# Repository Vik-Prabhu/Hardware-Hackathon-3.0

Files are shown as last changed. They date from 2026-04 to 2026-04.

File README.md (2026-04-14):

# 1. Title of the project
**Green Node**

# 2. Problem Statement
The global agricultural sector faces a massive adoption gap in precision agriculture. Out of over 500 million small farms globally, only about 10% use digital agricultural services.
- **Prohibitive Costs**: Commercial sensor nodes cost upwards of $200–$250 per unit, with traditional cellular IoT incurring high recurring costs and requiring expensive trenching.
- **Hardware Failures**: Many existing solutions fail in harsh agricultural environments, suffering from battery death during cold snaps or UV degradation.
- **Sensor Inaccuracies**: Low-cost sensors claim to measure nutrients but actually measure soil electrical conductivity, leading to high inaccuracies.
- **Data Fatigue**: Farmers are overwhelmed with raw data rather than actionable insights.
- **Yield vs. Money Disconnect**: Agritech often visualizes agronomy but fails to show economic impact.

# 3. Objective
To build a low-cost, scalable, and open-source plantation monitoring system for the Hardware Hackathon 3.0. Green Node merges robust hardware edge nodes with a sophisticated AI advisory pipeline to bring state-of-the-art agricultural monitoring to farmers. Our core objective focuses on plant survival, optimal yield, and early disease prevention through high-accuracy local ground truth.

# 4. Existing work
The current market is split between expensive agricultural tech and software-heavy platforms lacking local ground truth:
| Competitor | Approach | Weakness |
|---|---|---|
| **Fasal** | Farm-specific IoT | Very high hardware cost, vertical-specific |
| **CropIn** | Software-only platform | No on-ground sensors (estimations only) |
| **Manual Contractors**| Schedule-based inspection | Inefficient, unaccountable |

# 5. Gap analysis
Despite the rise of precision agriculture, competitors fail due to **scaling constraints and disconnected methodologies**. Existing systems lack integration between cheap continuous ambient measurement and deep-learning visual diagnostics. Solutions like Fasal capture field data but demand massive capital ($200+ unit cost), while CropIn relies purely on estimates without true real-world soil/plant mapping. 

Green Node bridges this gap by decoupling continuous soil telemetry from computationally heavy vision tasks—delivering a comprehensive package for under ₹2,400 per node, combined with actionable, real-time AI-guided triaging devoid of monthly LTE service drops.

# 6. Novelty
The core novelty resides in our **Dual-Node Architecture linked to an AI Advisory Pipeline**:
Instead of providing raw datasets like "humidity is 78%", Green Node features a visual capture layer. The camera node feeds leaf images into an AI model combined with live ambient data. The system generates intelligent, multi-lingual daily action priorities—e.g., *"Node 3 has early signs of Late Blight — inspect row 4."*
Additionally, we leverage **Dynamic Sentinal Polling**: Sensor nodes dynamically change their reporting frequency based on internal thresholds (e.g. accelerating ping rates from 30s to 5s during severe moisture drops).

# 7. Your project description
Green Node is a fully integrated ecosystem designed to deliver actionable intelligence. It incorporates:
1. **Hardware Edge Nodes:** Custom-designed PCB routing, deploying ESP32-C3 for continuous environmental tracking (temperature, humidity, moisture, light) and ESP32-CAM nodes for visual plant health assessments.
2. **Comprehensive Data Backend:** Built with FastAPI and an SQLite embedded database to handle data ingestion over local Wi-Fi without internet cellular reliance.
3. **AI Health Advisory Pipeline:** Contextually combined sensor data and visual image scans generate daily Action Plans translated into Tamil, Telugu, Kannada, Hindi, and Bengali using Sarvam AI, complete with audio TTS capabilities.
4. **Earthy Editorial Dashboard:** A fully responsive bespoke dashboard providing clear, animated, high-end insights for the modern facility or farmer.

# 8. List of components and the software used
### Hardware Components
* **MCU:** ESP32-C3 Dev Module (RISC-V) & AI-Thinker ESP32-CAM (ESP32-S).
* **Sensors:** DHT11 / DHT22 (Temperature & Humidity), Capacitive Soil Moisture Sensor v1.2, GL5528 LDR (Ambient Light), OV2640 (2MP Camera).
* **Power:** 5V/3.3V custom regulating PCB headers.

### Software Stack
* **Microcontroller Firmware:** C++ (Arduino Framework), `DHT sensor library`, `ArduinoJson`.
* **Backend Core:** Python (FastAPI, Uvicorn, APScheduler), SQLite.
* **Frontend Design:** Vue.js / VitePress / HTML interfaces.
* **Microservices:** Gemini Vision models natively proxied through a Sarvam AI API pipeline for multilingual translation and audio rendering.

# 9. Methodology
To validate our system in a real-world edge scenario, we deployed it in a live indoor bonsai nursery:
- **Node N-01 (Camera + Env Node):** Captured on-demand 800×600 SVGA SVGA imagery alongside DHT22 inputs whenever the server requested.
- **Node N-02 (Soil Node):** Pushed telemetry continuously every 30 seconds via HTTP POST, adjusting frequency whenever threshold rules were broken.
Data is sent explicitly through local WiFi `mDNS` structures routing directly to a secure, localized central Python Hub—acting as a firewall from public internet threats.

# 10. Work flow
1. **Boot Sequence:** Both nodes power up, synchronize UTC timing via NTP, and POST their IPs to `vikram-Vivobook-Go.local:8000/register`. 
2. **Measurement Cycle (Continuous):** The Soil Node (N-02) wakes, tracks variables, and evaluates internal thresholds to set loop delays (5s vs 30s) before executing an HTTP POST with JSON data.
3. **Capture Cycle (Pull):** The central server queries the Vision Node (N-01) at `GET /capture`. The node streams a JPEG byte packet alongside `X-Moisture` and `X-Temperature` custom headers.
4. **AI Inference & Translation:** The local Hub fuses the image and historical sensor values, passing it to an AI proxy. Sarvam AI retrieves the analysis, translating the diagnostic into local languages.
5. **Dashboard Reflection:** The end-user operates the Vue dashboard reading the localized `Daily Action Plan`.

# 11. Pic of the project/ prototype
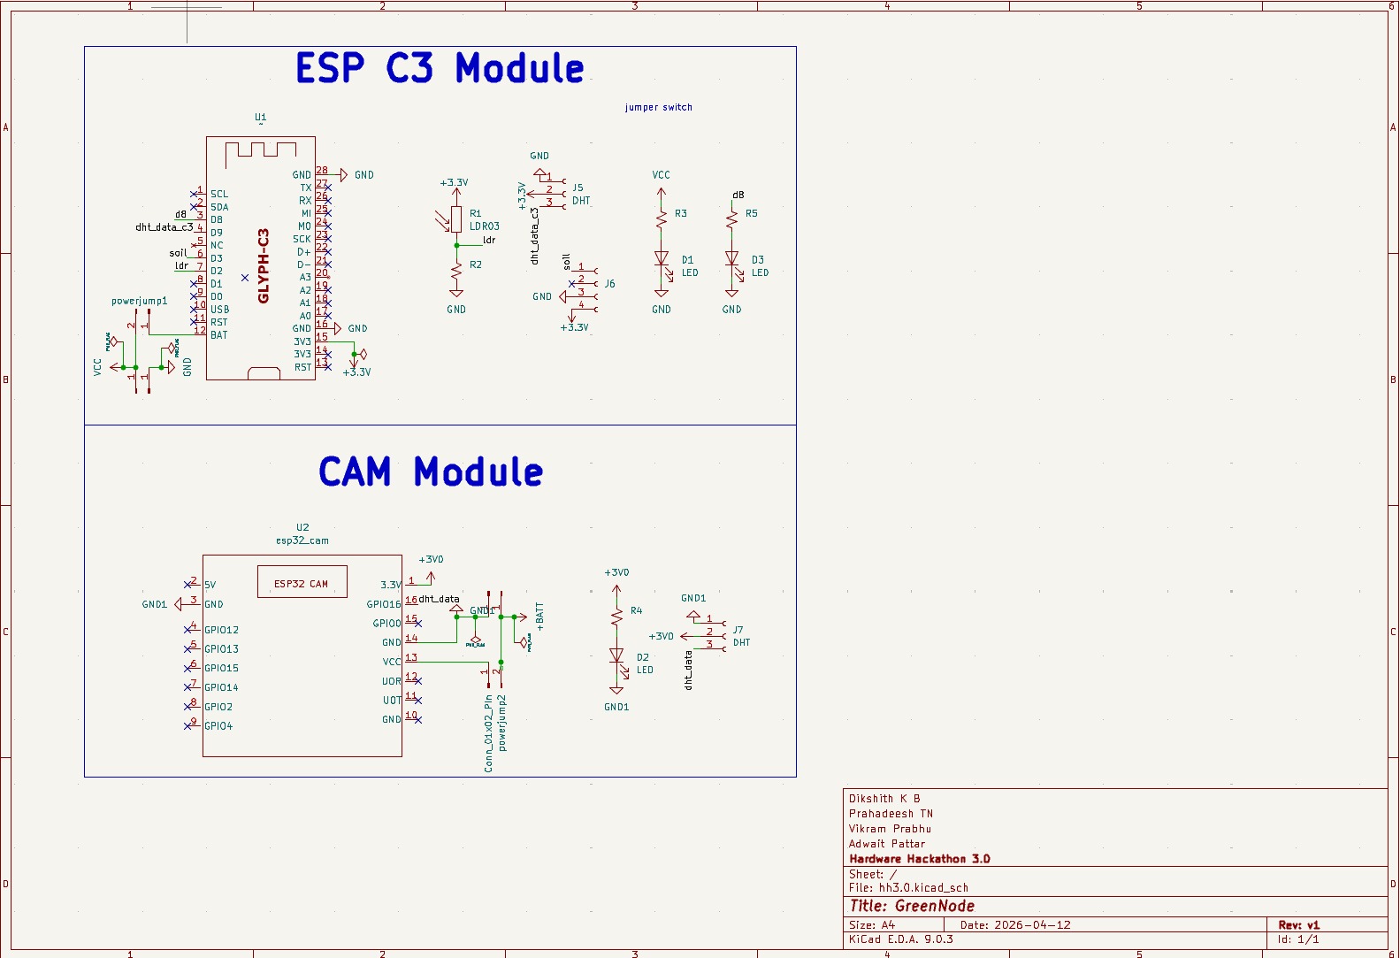
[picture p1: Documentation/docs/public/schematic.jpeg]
Green Node PCB Schematic

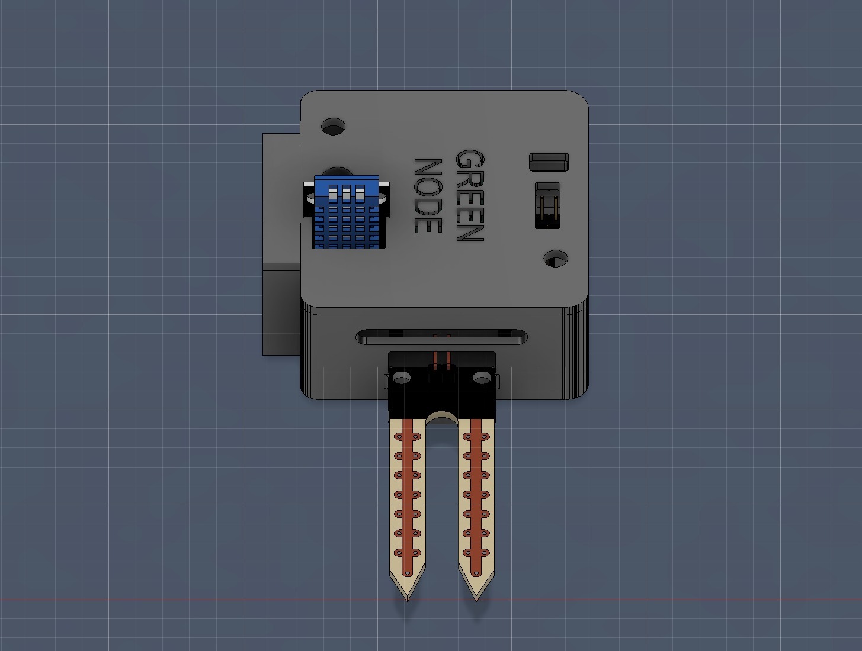
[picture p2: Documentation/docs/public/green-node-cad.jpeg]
Green Node CAD Housing


# 12. Demo video
*[Insert Link to Live Project Demo Video Here]*

# 13. Create a public github repo and attach the following
*The current repository encompasses the complete documentation, firmware, server environment, and backend code designed explicitly according to the 13-point rubric constraints.*
**Repository URL**: [https://github.com/Vik-Prabhu/Hardware-Hackathon-3.0](https://github.com/Vik-Prabhu/Hardware-Hackathon-3.0)

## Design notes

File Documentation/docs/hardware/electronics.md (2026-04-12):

# Electronics & Schematics

The Green Node PCB was designed in **KiCad 9.0.3** as a single-sheet schematic (`hh3.0.kicad_sch`) housing two independent sensor modules on one board. The design prioritises minimal component count, through-hole assembly, and modular sensor connectors.

## Full Schematic

Green Node PCB Schematic — Rev v1

---

## ESP C3 Module (Node N-02)

The upper section of the schematic is built around **U1 — GLYPH-C3**, an ESP32-C3 RISC-V module. It handles continuous soil, light, temperature, and humidity monitoring.

### Pin Assignments

| GLYPH-C3 Pin | Net | Connected To |
|:---:|---|---|
| D8 | `dB` | Status LED D3 via R5 (current-limiting) |
| D9 (dht_data_c3) | `dht_data_c3` | **J5** — DHT11 sensor, pin 2 (data) |
| A0 (soil) | `soil` | **J6** — Capacitive Soil Moisture Sensor, pin 1 (analog out) |
| A1 (ldr) | `ldr` | **R1 (LDR03)** — LDR voltage divider mid-point |
| D+ / D− | USB | On-board USB-C for programming |
| 3V3 | `+3.3V` | Regulated 3.3 V rail |
| GND | `GND` | Common ground |
| BAT | — | Battery input (unused in current revision) |

### Sensor Circuits

#### DHT11 — Temperature & Humidity (J5)
- **Connector:** 3-pin header (J5)
  - Pin 1 → `+3.3V`
  - Pin 2 → `dht_data_c3` (GPIO 9)
  - Pin 3 → `GND`
- **Pull-up:** R3 (10 kΩ) from data line to VCC

#### LDR — Ambient Light (R1)
- **R1 (LDR03)** forms a voltage divider with **R2** (10 kΩ fixed) between `+3.3V` and `GND`
- Mid-point tap connects to **A1** (GPIO 2) for analog read
- ADC maps the 0–3.3 V range to a 12-bit value (0–4095)

#### Capacitive Soil Moisture Sensor (J6)
- **Connector:** 4-pin header (J6)
  - Pin 1 → analog signal → `soil` (GPIO 3)
  - Pin 2 → `GND`
  - Pin 3 → `GND`
  - Pin 4 → `+3.5V` (sensor power)
- Corrosion-resistant capacitive probe; no direct soil contact on electrodes

#### Status LEDs (D1, D3)
- **D1** and **D3** are indicator LEDs driven through current-limiting resistors **R3** and **R5**
- Connected to GPIO `dB` for visual status feedback

### Power
- **powerjump1** — 2-pin power header providing `VCC` and `GND` from external supply
- **Jumper switch** at the top of the sheet controls main power to the C3 module
- The on-board LDO regulates input down to `+3.3V` for the MCU and sensors

---

## CAM Module (Node N-01)

The lower section is built around **U2 — ESP32-CAM** (AI-Thinker). It captures plant images on demand and reads ambient temperature via a DHT22 sensor.

### Pin Assignments

| ESP32-CAM Pin | Net | Connected To |
|:---:|---|---|
| 5V | `+5V` | External power input |
| GND | `GND1` | Common ground |
| 3.3V | `+3V0` | Regulated 3.3 V output |
| GPIO16 | `dht_data` | **J7** — DHT22 sensor, pin 2 (data) |
| GPIO0 | — | Boot mode select (active-low for flash) |
| U0R / U0T | UART | Serial programming via FTDI adapter |
| GPIO12–15, GPIO2, GPIO4 | — | Directly to camera data bus (active only on high-density header internally to the ESP32-CAM) |

### Sensor Circuits

#### DHT22 — Temperature & Humidity (J7)
- **Connector:** 3-pin header (J7)
  - Pin 1 → `GND1`
  - Pin 2 → `dht_data` (GPIO 16 → routed to GPIO 13 in firmware via internal mapping)
  - Pin 3 → `+3V0`
- **Pull-up:** R4 (10 kΩ) from data line to `+3V0`

#### Status LED (D2)
- Single indicator LED tied to `+3V0` through a current-limiting resistor
- Provides visual power-on feedback

### Power
- **powerjump2** — 2-pin Conn_01x02 header providing `+BATT` and `GND` from an external source
- The ESP32-CAM's on-board AMS1117 regulates 5 V input down to 3.3 V for the MCU and camera

::: warning Camera Pin Conflict
On the AI-Thinker ESP32-CAM, GPIOs 32–39 are **all consumed** by the OV2640 camera data bus. Analog sensors (soil moisture, LDR) cannot share this module and require an external I²C ADC (e.g. ADS1115) or a dedicated MCU like the GlyphC3 above.
:::

---

## Design Notes

| Parameter | Detail |
|---|---|
| **EDA Tool** | KiCad E.D.A. 9.0.3 |
| **Schematic File** | `hh3.0.kicad_sch` |
| **Sheet** | 1/1 (single sheet) |
| **Board Size** | A4 |
| **Revision** | v1 |
| **Date** | 2026-04-12 |
| **Designed by** | Dikshith K B, Prahadeesh TN, Vikram Prabhu, Adwait Pattar |

### Key Design Decisions
- **Modular sensor connectors (J5, J6, J7):** All sensors use standard pin headers so they can be swapped, replaced, or upgraded without rework
- **Separate power domains:** The C3 module runs on 3.3 V while the CAM module accepts 5 V, each with independent power jumpers for isolation during debugging
- **Through-hole assembly:** All connectors and passives are through-hole for ease of hand-soldering during rapid prototyping
- **Status LEDs on each module:** D1/D3 on the C3 side and D2 on the CAM side provide immediate visual feedback without requiring serial monitor access

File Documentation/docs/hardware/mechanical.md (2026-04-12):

# Mechanical Design

The mechanical design of the **Green Node** focuses on durability, compactness, and ease of assembly. The enclosure is designed to house the core electronics, sensors, and power management systems while providing adequate exposure out to the environment.

## 3D CAD Enclosure

The render below illustrates the assembly of the primary tracking node, integrating our key sensors directly into the structural housing.

Green Node CAD Assembly

### Mechanical Features
- **Integrated Environment Sensor (DHT11):** Protrudes gracefully from the side port to ensure the sensor captures ambient temperature and humidity seamlessly, free from any internal thermal interference.
- **Direct Soil Probing:** The soil moisture sensor is securely bottom-mounted, allowing the entire node to be easily pegged directly into the dirt.
- **Robust Casing:** The main body features heavy-duty styling with the "GREEN NODE" branding engraved cleanly on the surface.

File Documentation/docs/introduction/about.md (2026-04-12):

# About Our Project: Green Node

Welcome to **Green Node**, an advanced, open-source plantation monitoring system built for the Hardware Hackathon 3.0. We are building a comprehensive ecosystem that merges robust hardware edge nodes with a sophisticated AI advisory pipeline to bring state-of-the-art agricultural monitoring to your fingertips.

## Project Showcase

Our solution is divided into distinct, seamlessly integrated components:

### 1. Hardware Edge Nodes
At the core of the Green Node system are our custom-designed hardware nodes, leveraging reliable microcontrollers for real-world deployment:
- **GlyphC3 Sensor Nodes (ESP32-C3):** Engineered for continuous environmental tracking, these nodes gather precise temperature and humidity metrics using minimal power.
- **Vision Nodes (ESP32-CAM):** Equipped with camera modules, these nodes capture visual data of the plantation to enable visual health assessments.

### 2. Comprehensive Data Backend
Built with FastAPI and an SQLite embedded database, the robust backend architecture handles data ingestion from multiple distributed nodes via Wi-Fi network and HTTP. It offers a fully-featured RESTful API to manage the continuous stream of sensor metrics and images.

### 3. AI Health Advisory Pipeline
We integrate leading AI models to analyze the plantation's status:
- Using image and sensor data context, we generate a daily **AI Health Advisory** for the plantation.
- **Multilingual Support:** Powered by the Sarvam AI API, the dashboard provides a daily action plan translated into multiple regional languages, complete with integrated text-to-speech (TTS) playback to make the advisory accessible to every farmer.

### 4. Earthy Editorial Dashboard
All this data is visualized through our beautifully designed Green Node dashboard. Built with an earthy, modern, and editorial design language, the dashboard features:
- Interactive live sensor data
- Scroll-triggered animations and a premium glassmorphic UI
- Actionable AI-driven insights directly in the interface

We are passionate about bringing modern technology to agriculture efficiently, reliably, and elegantly. Explore the rest of the documentation to dive deeper into our hardware architecture, software stack, and implementation methodology!

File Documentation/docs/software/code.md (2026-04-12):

# Software & Firmware

> **Node Documentation** | ESP32-CAM & Soil Sensor Nodes
> 
> *Distributed passive system communicating via HTTP to a central Python server.*

---

# Software & Firmware

Two independent firmware builds run on two dedicated nodes. Both are passive — they respond
to the central Python server rather than pushing data on their own schedule.

**Camera Node** (AI-Thinker ESP32-CAM) — captures leaf images and ambient DHT22 readings on server trigger.

**Soil Node** (ESP32-C3) — continuously measures soil moisture, temperature, humidity, and light,
posting readings to the server on a dynamic interval.

---

## Part 1 — Camera Node (AI-Thinker ESP32-CAM)

### How It Works

The node connects to WiFi, registers its IP with the server, then idles — the loop only
handles incoming HTTP requests and retries registration if needed.

On `GET /capture` the node reads the DHT22, grabs a JPEG from the OV2640, streams the image
back as `image/jpeg`, and attaches sensor values as custom response headers.
No push, no polling loop — the server decides when to trigger.

### Configuration

```cpp
#define WIFI_SSID          "Vik"
#define WIFI_PASSWORD      "qwertyui"
#define SERVER_HOST        "vikram-Vivobook-Go.local"
#define SERVER_PORT        8000
#define NODE_ID            "N-01"
#define WIFI_CONNECT_TIMEOUT  20000
#define REGISTER_RETRY_DELAY  10000
```

`SERVER_HOST` is resolved via mDNS — the server machine must run Avahi (Linux) or Bonjour (macOS/Windows).

### GPIO Constraints

The OV2640 occupies GPIOs 0, 5, 18, 19, 21–27, 32, 34–36, 39 on the AI-Thinker board.
GPIOs 34–39 are also the ESP32's ADC1 pins, so **`analogRead()` cannot be used for any
analog sensor on this board.** The only free pin for an external sensor is **GPIO 13**,
used by the DHT22.

> Soil moisture and battery voltage require a separate node (Part 2) or an external
> I2C ADC (e.g. ADS1115). Currently `moisture` is aliased to DHT humidity and `battery`
> is hardcoded to `100.0`.

### DHT22 — GPIO 13

```cpp
#define DHT_PIN   13
#define DHT_TYPE  DHT22

float temperature = dht.readTemperature();
float humidity    = dht.readHumidity();

if (isnan(temperature)) temperature = 0.0;
if (isnan(humidity))    humidity    = 0.0;
```

Readings are taken synchronously inside `/capture`. The DHT22's 2-second minimum sample
interval is naturally respected since captures are server-triggered, not continuous.

### Camera Initialisation

Resolution and buffer count are chosen at runtime based on PSRAM availability:

```cpp
if (psramFound()) {
    config.frame_size   = FRAMESIZE_SVGA;   // 800×600
    config.jpeg_quality = 12;
    config.fb_count     = 2;
} else {
    config.frame_size   = FRAMESIZE_VGA;    // 640×480
    config.jpeg_quality = 14;
    config.fb_count     = 1;
}
```

SVGA is preferred over UXGA — higher resolutions cause allocation failures on this board
without PSRAM. Clock is set to 10 MHz (default is 20 MHz) to reduce heat on the module.

After init, auto-exposure, auto-gain, and auto-white-balance are enabled via the sensor register
API. Five warm-up frames are then discarded to let AEC and AWB settle.

### HTTP Endpoints

#### `GET /capture`

1. Returns `503` immediately if a capture is already in progress
2. Reads DHT22
3. Calls `esp_camera_fb_get()` — retries once with a 500 ms delay on failure
4. Sends JPEG with sensor data as response headers
5. Returns frame buffer and clears the `capturing` flag

```cpp
localServer.sendHeader("X-Moisture",    String(moisture, 1));
localServer.sendHeader("X-Temperature", String(temperature, 1));
localServer.sendHeader("X-Battery",     String(battery, 1));
localServer.sendHeader("X-Node-ID",     NODE_ID);
```

Image is streamed in 4096-byte chunks to avoid stalling the WiFi stack.

Possible responses: `200 image/jpeg` on success, `500` if the camera failed, `503` if busy.

#### `GET /health`

Liveness check — no capture triggered. Returns:

```json
{
  "node_id": "N-01",
  "camera": true,
  "capturing": false,
  "uptime": 3742,
  "free_heap": 186432,
  "ip": "192.168.1.105"
}
```

### Server Registration

On boot (and every 10 s while unregistered), the node POSTs its IP:

```
POST http://vikram-Vivobook-Go.local:8000/node/N-01/register
{"ip": "192.168.1.105"}
```

If the server is offline at boot, the node retries silently until it responds.
WiFi drops also reset `registered = false`, triggering re-registration after reconnect.

### Flashing

**Arduino IDE dependencies:** `esp32` board package (Espressif, v2.0.x+),
`DHT sensor library` by Adafruit, `Adafruit Unified Sensor`.

**Board settings:** AI Thinker ESP32-CAM · Upload Speed 115200 · Partition: Huge APP (3MB No OTA).

The ESP32-CAM has no onboard USB. Wire an FTDI FT232RL adapter:

```
FTDI 3.3V  →  ESP32-CAM 3.3V
FTDI GND   →  ESP32-CAM GND
FTDI TX    →  GPIO 3  (U0R)
FTDI RX    →  GPIO 1  (U0T)
FTDI GND   →  IO0     ← hold LOW during flash only
```

Hold IO0 low → press reset → upload → disconnect IO0 → press reset to run.

---

## Part 2 — Soil Sensor Node (ESP32-C3)

### How It Works

Unlike the camera node, the soil node is **push-based** — it wakes on a timer, reads all
four sensors, and POSTs a JSON payload to the server. The send interval is dynamic:
30 seconds under normal conditions, dropping to 5 seconds when soil moisture goes critical.
The server can also override the interval by returning a `next_sleep_min` field in its response.

### Configuration

```cpp
#define PIN_SOIL_MOISTURE   3
#define PIN_LDR             2
#define PIN_DHT             9
#define DHT_TYPE            DHT11

#define SEND_INTERVAL_NORMAL_MS    (30UL * 1000)
#define SEND_INTERVAL_CRITICAL_MS  (5UL  * 1000)
#define MOISTURE_CRITICAL          25

#define WIFI_SSID     "Vik"
#define WIFI_PASSWORD "qwertyui"
#define SERVER_HOST   "vikram-Vivobook-Go.local"
#define SERVER_PORT   8000
#define NODE_ID       "N-02"
```

### Sensors

#### Soil Moisture — GPIO 3 (analog)

Raw ADC output (0–4095) is mapped to a 0–100% scale and inverted — higher raw value
means drier soil on a resistive sensor:

```cpp
int rawSoil   = analogRead(PIN_SOIL_MOISTURE);
data.moisture = (float)constrain(map(rawSoil, 4095, 0, 0, 100), 0, 100);
```

#### Temperature & Humidity — DHT11 on GPIO 9

```cpp
data.humidity    = dht.readHumidity();
data.temperature = dht.readTemperature();
if (isnan(data.humidity))    data.humidity    = 0.0;
if (isnan(data.temperature)) data.temperature = 0.0;
```

Note: DHT11 is used here (not DHT22) — ±2°C and ±5% RH accuracy. Upgrade to DHT22 for
tighter tolerances.

#### Light — LDR on GPIO 2 (analog, GL5528-style)

The LDR sits in a voltage divider with a 100 kΩ pull-down resistor. The ADC reading is
converted to lux through three steps:

```cpp
// 1. ADC counts → voltage at the ADC pin
float v_adc = rawLDR * (LDR_SUPPLY_V / 4095.0f);

// 2. Voltage divider → LDR resistance (LDR between VCC and ADC pin)
float r_ldr = (v_adc > 0.01f)
              ? LDR_PULLDOWN_OHM * (LDR_SUPPLY_V - v_adc) / v_adc
              : 1000000.0f;  // clamp in total darkness

// 3. Power-law model → Lux
// GL5528 characteristic: R_ldr = A × lux^B  →  lux = (R_ldr / A)^(1/B)
float lux = pow(r_ldr / LDR_A, 1.0f / LDR_B);
lux = constrain(lux, 0.0f, 100000.0f);
data.light = (int)lux;
```

Power-law constants used:

```cpp
#define LDR_A  32017.558f   // resistance at reference illuminance (Ω)
#define LDR_B  -0.7f        // slope exponent (negative: more light = less resistance)
```

These are fit to a GL5528 characteristic curve. Recalibrate `LDR_A` and `LDR_B` against
a reference lux meter if accuracy matters.

#### Battery

Currently hardcoded to `100`. Replace with a real ADC read through a resistor divider
when a battery circuit is added.

### Dynamic Send Interval

After every read, the node checks moisture against the critical threshold and adjusts
its interval before posting:

```cpp
sendIntervalMs = (sd.moisture < MOISTURE_CRITICAL)
                 ? SEND_INTERVAL_CRITICAL_MS    // 5 s
                 : SEND_INTERVAL_NORMAL_MS;     // 30 s
```

The server can also push an interval override in the POST response:

```json
{ "next_sleep_min": 10 }
```

If present, `next_sleep_min` (in minutes) overrides the local calculation for the next cycle.

### HTTP POST — `/node/N-02/sensor`

```json
{
  "moisture":    45.0,
  "temperature": 26.2,
  "humidity":    60.0,
  "light":       3200,
  "battery":     100.0,
  "timestamp":   "2026-04-11T12:00:00Z"
}
```

`timestamp` is an ISO 8601 UTC string generated from NTP-synced system time.
If the POST fails, the node retries once after 1 second before moving on.

### NTP Time Sync

The node syncs its clock immediately after WiFi connects in `setup()`:

```cpp
configTime(0, 0, "pool.ntp.org", "time.nist.gov");
```

Timestamps are formatted as ISO 8601 UTC:

```cpp
char buf[25];
strftime(buf, sizeof(buf), "%Y-%m-%dT%H:%M:%SZ", &t);
```

If NTP fails (10-second timeout), timestamps fall back to `"1970-01-01T00:00:00Z"`.

### Main Loop

```cpp
void loop() {
  if (millis() < nextSendTime) return;  // idle until interval expires

  ensureWiFiConnected();
  SensorData sd = readSensors();

  // pick interval based on moisture level
  sendIntervalMs = (sd.moisture < MOISTURE_CRITICAL)
                   ? SEND_INTERVAL_CRITICAL_MS
                   : SEND_INTERVAL_NORMAL_MS;

  long serverInterval = sendData(sd);
  if (serverInterval == -1) {          // retry once on failure
    delay(1000);
    serverInterval = sendData(sd);
  }
  if (serverInterval > 0)
    sendIntervalMs = (unsigned long)serverInterval;

  nextSendTime = millis() + sendIntervalMs;
}
```

The loop body runs only when `millis()` reaches `nextSendTime` — no `delay()` blocking,
no RTOS tasks. WiFi reconnection is handled inline before every read cycle.

### Flashing

**Arduino IDE dependencies:** `esp32` board package (Espressif), `DHT sensor library` by Adafruit,
`Adafruit Unified Sensor`, `ArduinoJson` by Benoit Blanchon.

**Board settings:** ESP32C3 Dev Module · Upload Speed 115200 · USB CDC On Boot: Enabled.

The ESP32-C3 has a native USB-Serial bridge — no FTDI adapter needed. Connect via USB,
select the correct COM port, and upload directly.

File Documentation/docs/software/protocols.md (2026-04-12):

# Communication Protocols

This document outlines the architecture, data flows, and security mechanisms of the communication protocols utilized in the Hardware Hackathon system.

## 📡 Core Protocol Architecture

The system operates primarily on **HTTP/1.1** over IPv4 TCP/IP, broadcasted over an IEEE 802.11 (WiFi) local network. We chose standard HTTP for its simplicity, ease of debugging, and strong compatibility with the FastAPI backend and ESP32 `WebServer` / `HTTPClient` frameworks.

In addition to HTTP, **mDNS (Multicast DNS)** is optionally configured for localized server-node discovery without hardcoding dynamic IPs.

### Protocol Breakdown

#### 1. Node-to-Server Data Transmission (HTTP POST)
- **Data Format**: JSON Payload
- **Role**: ESP32 nodes periodically acquire sensor data (temperature, humidity, moisture, light) and serialize it.
- **Endpoint**: `/node/{node_id}/sensor`
- **Mechanism**: The ESP32 node acts as an HTTP client, making asynchronous `POST` requests to the FastAPI backend. Nodes also announce their presence via a periodic `/node/{node_id}/register` ping so the server can track dynamic local IP assignments.

#### 2. Server-to-Node Polling (HTTP GET)
- **Data Format**: Image stream (JPEG/Multipart) & Metadata in Custom HTTP Headers
- **Role**: The backend server can remotely trigger a photo capture for vision-enabled nodes (`esp32cam_node`).
- **Endpoint (on Node)**: `http://{node_ip}/capture`
- **Mechanism**: The FastAPI server acts as an HTTP Client, sending requests to the embedded WebServer concurrently running on the ESP32. The node replies with a raw JPEG byte stream. Essential sensor metadata is bundled directly into the outbound `HTTP Headers` (e.g., `X-Moisture`, `X-Temperature`) to save bandwidth and simplify parsing.

#### 3. Client-to-Server Dashboard API (HTTP)
- **Data Format**: RESTful JSON API
- **Role**: The VitePress front-end dashboard fetches historical logs, AI advisories, real-time alerts, and captures.
- **Mechanism**: Standard `GET` and `POST` requests utilizing browser-native `fetch`.

#### 4. Server-to-AI Microservices (HTTP / HTTPS)
- **Data Format**: JSON & Multipart Form Data
- **Role**: Offloads logic to heavier deep-learning models for image/sensor analysis and multi-lingual translation.
- **Mechanism**:
  - **Internal AI API**: The backend forwards hardware requests to the local `AI_SERVER_URL` via proxy requests.
  - **External Cloud API**: Sarvam AI text translations are sent securely over the Wide Area Network (WAN) via `HTTPS` (`https://api.sarvam.ai/translate`).

---

## 🔒 Security & Safety Mechanisms

Given the constraints of Internet of Things (IoT) environments, network safety requires a combination of boundary fortification and internal resilience. Because this project is designed as an open-source, edge-computing blueprint deployed on private spaces, we prioritize internal segmentation and logical boundaries.

### 1. Isolated Network Topology
The sensor nodes are **never** exposed directly to the public internet. All nodes communicate *only* with the local Gateway (FastAPI server). The backend proxy acts as a firewall and orchestrator, shielding the microcontrollers from external attacks, port scanning, or malicious polling.

### 2. Transport Layer Security (HTTPS vs. HTTP)
- **Local Network**: Inter-node communication (ESP32 ↔ Local Server) uses plain `HTTP`. In heavily constrained devices (like standard ESP32 boards), encrypting every localized TCP packet payload incurs significant computational overhead, which drains battery and introduces latency. We mitigate the risk by relying entirely on the base **WPA2/WPA3 Wi-Fi encryption**. Packet-sniffing requires first circumventing the wireless router's security layer.
- **Outbound Traffic**: Any communication leaving the local edge network to hit external endpoints (e.g., the Sarvam AI Language API) is fully secured using **HTTPS (TLS 1.2/1.3)** to prevent MiTM (Man in the Middle) interception.

### 3. Rate Limiting and Resilience
- **Node Side (Non-Blocking)**: The firmware leverages a hardware timer & `millis()` architecture rather than `delay()`. If the server drops offline or an HTTP timeout occurs, the node gracefully abandons the connection and continues acquiring hardware metrics without freezing the execution loop.
- **Server Side (Asynchronous)**: The FastAPI server applies decoupled asynchronous handlers (`aiohttp`) with strict lifecycle bounds (e.g., local `ClientTimeout`). If an ESP32 node hangs mid-transmission due to signal attenuation, the server proactively drops the connection, preventing resource exhaustion and blocking.

### 4. Codebase Credential Hardening
- Platform secrets—like the `SARVAM_API_KEY` and remote endpoints `AI_SERVER_URL`—are kept strictly decoupled via environment variables (`.env`).
- Environment templates are inherently shielded. `git` enforces ignorance of `.env` files, prohibiting source-code credential leakage to GitHub. No sensitive token is embedded into the compiled Arduino binaries either.

---

## 📝 Network Flow Diagram

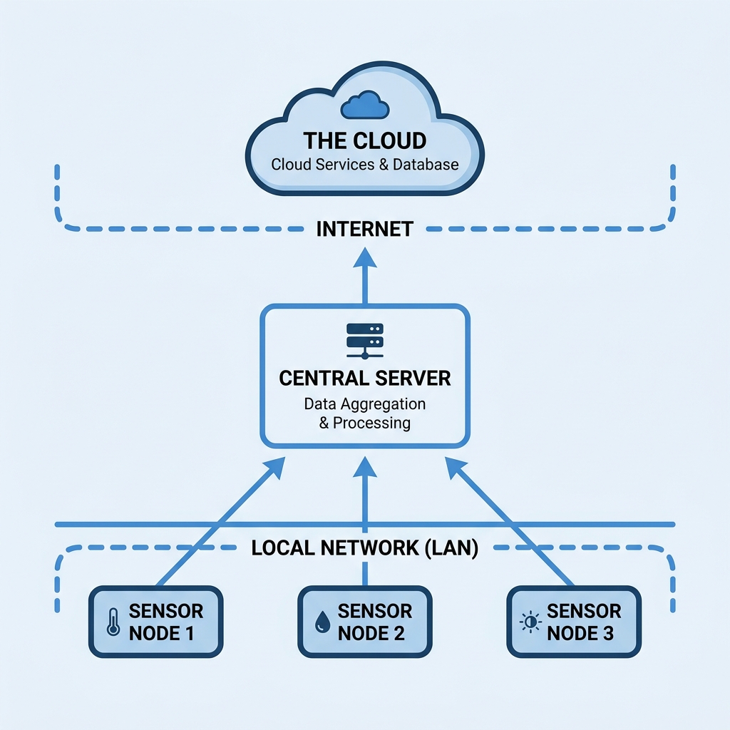
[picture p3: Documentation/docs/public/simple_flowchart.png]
Network Flowchart


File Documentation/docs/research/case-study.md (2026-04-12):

---
title: From Prototype to Product
description: How we evaluated our plant health monitoring system against a real-world product framework
sidebar_position: 3
---

# From Prototype to Product

Building something that works in a hackathon and building something that works in a field
for a paying customer are very different problems. This section documents how we stress-tested
our system against a structured product thinking framework — to be honest about what we've
built, what it's missing, and how it could scale.

---

## The Three Lenses

We evaluated the system through three lenses before calling it a product.

**Customer Lens** — Does it actually help the user succeed?
Our target users are farmers and greenhouse managers who don't have time for manual
crop inspection. The system needs to surface the right information at the right time,
without requiring the user to interpret raw sensor data themselves.

**System Lens** — Does it work reliably in the real world?
Because the hardware lives outdoors in soil and weather, reliability is non-negotiable.
A sensor that fails after two rain cycles is worse than no sensor — it creates false confidence.
Every design decision around enclosures, waterproofing, and sensor selection traces back to this.

**Business Lens** — Will users pay for it, and keep paying?
An AI insight that replaces a single agronomist visit has clear economic value.
We need to make sure the system delivers that value consistently enough that it becomes
a recurring part of how a farm operates, not a one-time experiment.

---

## What We're Actually Selling (Kotler's Product Model)

Mapping the system to Kotler's three-layer model forced us to be precise about
where our differentiation actually sits.

**Core Benefit**
Plant survival, optimal yield, and early disease prevention. This is the need we're selling
against — not hardware, not software.

**Expected Product**
At minimum, buyers expect the physical nodes to reliably capture soil moisture, temperature,
humidity, and light data. This is table stakes — any competitor can offer this.

**Augmented Product — our actual differentiator**
The camera node feeding leaf images into a pre-trained AI disease detection model is what
moves us out of the commodity tier. Instead of telling a farmer "humidity is 78%",
we tell them "Node 3 has early signs of Late Blight — inspect row 4."
That specificity is what justifies a price premium and creates switching costs.

---

## Architecture for Scale

We designed the system in three tiers so it can grow without a full rebuild.

**Tier 1 — Smart Connected Product**
Individual sensor nodes and camera nodes gathering real-time soil and plant data.
This is what we've built and what the MVP ships.

**Tier 2 — Product System**
A centralised platform where data from multiple nodes and the AI model aggregate
into a single farm health dashboard. Multiple farms, multiple node clusters,
unified view — this is the next 6-month target.

**Tier 3 — System of Systems (future)**
Integration with external data sources: weather APIs, automated irrigation controllers,
ERP systems used by large agricultural operations. The soil moisture reading triggers
a watering event. The disease detection flags a spray order. At this tier, the system
becomes infrastructure rather than a product.

---

## MVP Scope — MoSCoW Prioritisation

We used MoSCoW to define what Day 1 of a real deployment must include vs. what can wait.

**Must Have**
Soil moisture sensing accurate enough to trigger meaningful alerts.
AI leaf analysis that correctly identifies the most common disease classes.
A server that stores readings and surfaces alerts — even if the dashboard is basic.
Nodes that survive rain and outdoor temperatures for at least one growing season.

**Should Have**
Ambient humidity and light sensing for richer context around moisture readings.
NTP-synced timestamps so data aligns across multiple nodes.
Dynamic send intervals so the system reports more frequently when conditions are critical.

**Could Have**
Predictive disease modelling using time-series soil data, not just snapshot leaf images.
Battery voltage monitoring and low-battery alerts.
OTA firmware updates so deployed nodes don't need physical access to update.

**Won't Have (this iteration)**
LoRa or cellular connectivity — the current system requires local WiFi.
Automated irrigation actuation — we send alerts, we don't yet trigger hardware responses.
Full regulatory certification (CE, FCC) required for commercial distribution.

---

## Hardware Reality

Because we're shipping physical nodes, not just software, the manufacturing constraints
are part of the product definition — not an afterthought.

Components were chosen for immediate availability on standard supplier catalogues
(LCSC, Mouser, DFRobot) so the BOM can be sourced without long lead times.
The AI-Thinker ESP32-CAM and ESP32-C3 are both in mass production with stable supply.

For future commercial distribution, wireless modules operating in the 2.4 GHz and
sub-GHz bands require regional certification — CE for Europe, FCC for North America,
WPC for India. This is planned for after the MVP validation phase, once the core product
has been tested across at least two growing seasons in real field conditions.

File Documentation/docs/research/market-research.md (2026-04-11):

# Market Research & Business Plan

## Market Overview & Demand Drivers
The global agricultural and agritech sector is undergoing a massive transformation. Valued at approximately **$27.38 billion in 2023**, the market is projected to skyrocket to **$108.17 billion by 2032**. 
This growth is fundamentally driven by a surging global population—expected to reach 9.7 billion by 2050—which will require a 70% increase in food production. Simultaneously, maintaining green infrastructure and agricultural yields is increasingly challenging due to climate change, water scarcity, and declining pollinator populations.

## Gap in the Market: Why Competitors Fail
Despite the rise of precision agriculture, there is a massive adoption gap. Globally, out of over 500 million small farms, **only about 10% of smallholder farmers use digital agricultural services**. This gap is driven by critical pain points that Green Node is positioned to solve:

- **Prohibitive Costs & Scalability:** Commercial sensor nodes often cost upwards of $200–$250 per unit, making them inaccessible for large-scale deployments. Furthermore, traditional cellular IoT networks (LTE-M/NB-IoT) incur high recurring costs ($2–$10 per device monthly), and deploying grid power requires expensive trenching ($5,000–$25,000 per remote node).
- **Hardware Failures in the Field:** Many existing solutions fail in harsh agricultural environments. Battery-only sensors easily die during cold snaps, requiring expensive manual labor to replace them. Cheap solar panels rely on PET lamination that degrades and yellows within 18 months due to pesticide and UV exposure.
- **Sensor Inaccuracies:** The market is flooded with low-cost "NPK" sensors that claim to measure nutrients but actually just measure soil electrical conductivity, leading to highly inaccurate readings unless rigorously calibrated to specific local soils.
- **"Data Fatigue" & Poor UI/UX:** Farmers and facility managers are overwhelmed with raw data (e.g., raw soil moisture percentages) rather than actionable insights, leading to alert fatigue. Standard tech interfaces fail in the field because they lack offline functionality for connectivity "dead zones" and use interfaces that wash out under the harsh glare of midday sun.
- **The "Yield vs. Money" Disconnect:** Most Agritech apps excel at visualizing agronomy but fail to show the economic impact. A field might show "green" for health, but if the chemical inputs cost more than the saved crop, the user loses money.

## Target Market & Segments
Green Node addresses the inefficiency of schedule-based plant maintenance across multiple high-value segments:
- **Highway Medians (NHAI / PWD):** Replacing expensive tanker trips with data-driven irrigation across public infrastructure.
- **Commercial Nurseries:** Protecting high-value plant stock, reducing labor waste, and aiding export compliance through automated logs.
- **Urban Parks & Campuses:** Creating accountability for municipal contractors and large facilities with low staff overhead.
- **Controlled Environments:** Rooftop gardens and greenhouses requiring remote monitoring and precision care without on-site gardeners.

## Competitive Landscape
The current market is split between expensive agricultural tech and software-heavy platforms lacking local ground truth.

| Competitor | Approach | Weakness | Green Node Advantage |
|---|---|---|---|
| **Fasal** | Farm-specific IoT | Very high hardware cost, vertical-specific | General purpose, sub-₹2,400 node |
| **CropIn** | Software-only platform | No on-ground sensors (estimations only) | Actual sensor ground-truth |
| **Manual Contractors**| Schedule-based inspection | Inefficient, unaccountable | Route optimization & actionable data trail |

## SWOT Analysis

### Strengths
- **Low Hardware Cost:** Full node under ₹2,400; deployable at scale without massive upfront capital.
- **API & Sensor Synergy:** Combines real soil data with weather APIs for hyper-accurate, rain-aware irrigation.
- **Labor Optimization:** Route optimization solves a major workforce inefficiency (achieving ~75% time savings per shift), effectively tackling alert fatigue.

### Weaknesses
- **Sensor Tolerance Limits:** DHT11 ±2°C/±5% RH accuracy degrades in sustained high-humidity; demands upgrade (DHT22/SHT31) for extensive long-term deployments.
- **Local Range Constraints:** ESP-NOW caps at ~200m; requires relay modules for dispersed highway corridors.

### Opportunities
- **Government Procurement:** Active NHAI/PWD smart highway and green infrastructure mandates.
- **Export Compliance Tier:** Phytosanitary logs can unlock premium EU/US markets for partner nurseries.
- **Corporate ESG Integration:** Sponsored nodes for highway greenery by adjacent corporations seeking tangible CSR impact.

### Threats
- **Slow Sales Cycles:** Municipal or government procurement channels typically involve 12–18 month delays.
- **Environmental Hazard & Vandalism:** Nodes deployed in public spaces must endure physical tampering and brutal Indian monsoons (IP65 enclosures are critical).

## Financial Model & Cost Breakdown

**Unit Economics**
- **Grid-Powered Node:** ₹1,690 
- **Solar-Ready Node:** ₹2,790
- *Payback Period:* ~5 months assuming baseline SaaS pricing.

**Revenue Streams**
1. **Pilot Deployment (₹2–5 Lakh):** Initial 10 nodes including hardware, full installation, and 6-month dashboard data access.
2. **Subscription SaaS (₹500–800/node/month):** Predictable recurring revenue for dashboard, route prioritization, and automated alerts.
3. **Performance Contracts:** Revenue sharing model capturing 20% of the proven water bill reductions.
4. **Maintenance SLAs:** Annual hardware calibration and premium compliance reporting tiers.

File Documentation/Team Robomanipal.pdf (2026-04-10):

# Team RoboManipal

### Objective

We are building NurseryHub, an offline edge AI system that monitors every plant as an individual. We will design and implement a system capable of monitoring, maintaining, and controlling environmental conditions for plants within a nursery.

### Abstract and Plan

India has over 50,000 registered nurseries, the majority operating with fewer than five staff. Ornamental horticulture, tissue culture labs, bonsai collections, and grafting research stations all face the same constraint: biological systems with individual needs, managed by people whose attention is finite. GroveOS is not a gadget for a single plant on a windowsill. It is infrastructure for anyone who grows living things at scale and cannot afford to lose them.

A Maidenhair fern (Adiantum) can collapse in four hours when its soil dries below 60% in a nursery, whereas the Haworthia two benches over can tolerate 15% moisture for two weeks without complaining. The rootstock of a grafted rose requires a different level of hydration than the scion. If the temperature rises by two degrees above its comfortable range, a bud-set gardenia will abort every flower.

Soil moisture, temperature, humidity, ethylene, and CO2 are continuously measured by a network of modularized MCU nodes. The SBC hub fits a moisture decay curve to each plant's history to predict "water in 4 hours" rather than "water now," applies per-species thresholds (Calathea at 18% moisture fires an alert while cactus at 18% does not), and spreads disease risk through a spatial adjacency graph so that neighbors of a sick plant are flagged proactively before symptoms appear.

Sensors Sub Category Used-

- Temperature & Humidity
- Light & Colour
- Sound & Vibration
- Gas & Air Quality
- Soil & Moisture

Every morning the hub outputs a numbered walk route, the shortest path through all flagged plants, so two staff manage 200 plants purposefully instead of wandering.

The expected outcome is a nursery operating on a predictive rather than reactive model, with alert fatigue eliminated, disease spread caught early, and daily inspection time cut from two hours to under thirty minutes.

### Concept Category

- Microcontroller - ESP32
- SBC - Raspberry Pi
- Sensors - soil/moisture, temperature/humidity, gas/air quality
- Communication - Wi-Fi and BT
- Display - LCD
- Output Devices - addressable LED strips.

### Block Diagram

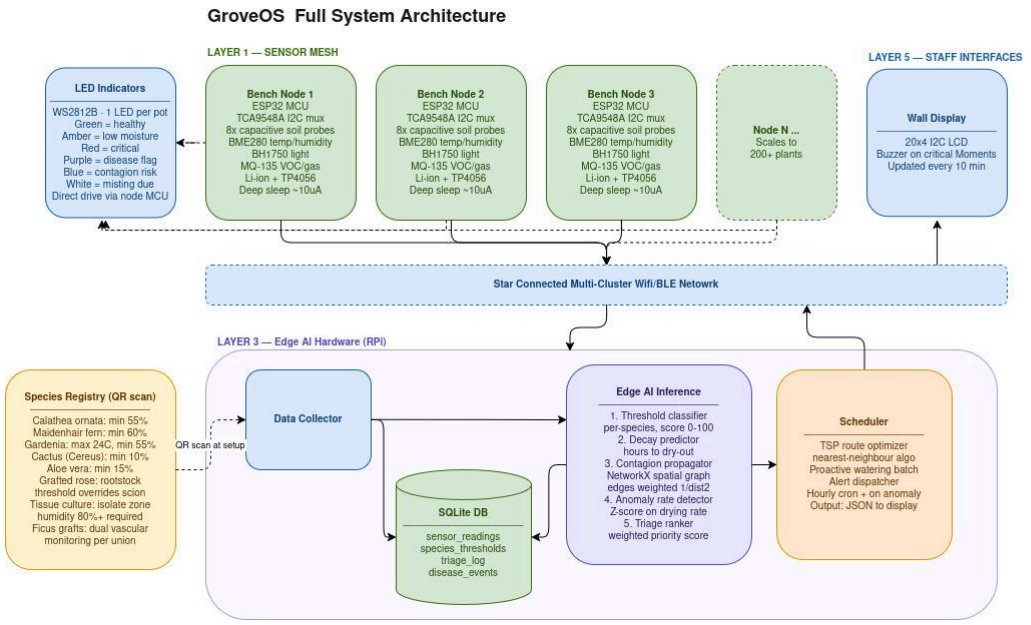
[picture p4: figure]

### Adaptability Statement

There are multiple parameters to judge plant health hence the sensors can be changed depending upon the need. If soil probes are unavailable we shift to temperature and gas sensors as primary health proxies.

If the product category shifts away from agriculture entirely, the same architecture distributed sensor nodes, a central inference hub, a route optimised output applies directly to warehouse inventory monitoring, server room environmental management, or hospital bed condition tracking.

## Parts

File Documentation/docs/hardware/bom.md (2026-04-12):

# Bill of Materials

A complete list of components required to build the **Green Node** plantation monitoring system. The BOM is organized by node type and shared infrastructure.

---

## Node N-01 — Camera + Environment Node

This node uses an **ESP32-CAM (AI-Thinker)** as its MCU. It captures plant images for AI-powered health analysis and reads ambient temperature & humidity via a DHT22 sensor.

| # | Component | Specification | Qty | Purpose |
|---|---|---|:---:|---|
| 1 | ESP32-CAM (AI-Thinker) | ESP32-S, OV2640 camera, 4 MB PSRAM | 1 | MCU + image capture |
| 2 | OV2640 Camera Module | 2 MP, SVGA (800×600) / VGA (640×480) | 1 | Plant health imaging *(included with ESP32-CAM board)* |
| 3 | DHT22 (AM2302) | Digital temp & humidity sensor, ±0.5 °C / ±2 % RH | 1 | Ambient temperature & humidity on GPIO 13 |
| 4 | FTDI / USB-TTL Adapter | 3.3 V logic, CP2102 or CH340 | 1 | Programming (ESP32-CAM has no on-board USB) |
| 5 | 5 V Power Supply / USB Cable | 5 V ≥ 500 mA | 1 | Board power |
| 6 | 10 kΩ Resistor | ¼ W, through-hole | 1 | DHT22 pull-up on data line |
| 7 | Jumper Wires | Male-to-Female, assorted | ~6 | Signal wiring |
| 8 | Breadboard / Perfboard | Half-size or full-size | 1 | Prototyping base |

> **Note:** On the AI-Thinker ESP32-CAM, GPIO 32–39 are consumed by the camera data bus. Analog sensors (soil moisture, LDR) require an external I²C ADC (e.g. ADS1115) or a separate MCU if added to this node.

---

## Node N-02 — GlyphC3 Sensor Node

This node uses an **ESP32-C3** (RISC-V) as its MCU. It continuously reads soil moisture, ambient light, temperature, and humidity, then transmits readings over Wi-Fi to the backend server.

| # | Component | Specification | Qty | Purpose |
|---|---|---|:---:|---|
| 1 | ESP32-C3 Dev Board | RISC-V single-core, Wi-Fi, 12-bit ADC | 1 | MCU + wireless comms |
| 2 | DHT11 | Digital temp & humidity sensor, ±2 °C / ±5 % RH | 1 | Temperature & humidity on GPIO 9 |
| 3 | Capacitive Soil Moisture Sensor v1.2 | Analog output, corrosion-resistant | 1 | Soil moisture on GPIO 3 (ADC) |
| 4 | LDR (Light-Dependent Resistor) | 5 mm, CdS photoresistor | 1 | Ambient light level on GPIO 2 (ADC) |
| 5 | 10 kΩ Resistor | ¼ W, through-hole | 2 | LDR voltage divider + DHT11 pull-up |
| 6 | USB-C Cable | Data + power | 1 | Programming & power supply |
| 7 | Jumper Wires | Male-to-Female, assorted | ~8 | Signal wiring |
| 8 | Breadboard / Perfboard | Half-size | 1 | Prototyping base |

---

## 3D-Printed Enclosure

Custom housing designed to protect the electronics while exposing sensors to the environment. See the [Mechanical Design](/hardware/mechanical) page for the full CAD render.

| # | Component | Specification | Qty | Purpose |
|---|---|---|:---:|---|
| 1 | 3D-Printed Enclosure Body | PLA / PETG, branded "GREEN NODE" | 1 per node | Weatherproof housing |
| 2 | Side Port Cover | PLA / PETG, snap-fit | 1 per node | DHT sensor access slot |
| 3 | M3 × 8 mm Screws | Stainless steel, Phillips | 4 per node | Enclosure assembly |

---

## Shared Infrastructure / Server

The backend runs on a local machine (e.g. laptop) and hosts the FastAPI server, SQLite database, dashboard, and AI analysis pipeline.

| # | Component | Specification | Qty | Purpose |
|---|---|---|:---:|---|
| 1 | Server Machine | Any laptop/PC running Python 3.10+, Wi-Fi enabled | 1 | FastAPI backend + dashboard host |
| 2 | Wi-Fi Router / Hotspot | 2.4 GHz, WPA2 | 1 | Local network for node–server comms |
| 3 | AI Processing Server *(optional)* | GPU-enabled machine with Gemini API access | 1 | Runs the plant health advisory model |

---

## Summary & Cost Estimate

| Assembly | Key Components | Est. Cost (₹) |
|---|---|---:|
| **N-01** — Camera Node | ESP32-CAM, DHT22, FTDI adapter | ~₹750 |
| **N-02** — Sensor Node | ESP32-C3, DHT11, Soil Moisture, LDR | ~₹550 |
| **Enclosure** (per node) | 3D print filament + fasteners | ~₹100 |
| **Infrastructure** | Wi-Fi router, server laptop | *Existing* |
| | **Total (2-node system)** | **~₹1,500** |

::: tip Scalability
Additional sensor nodes can be added by flashing the GlyphC3 firmware with a unique `NODE_ID` (e.g. `N-03`, `N-04`, …). Each new node costs approximately **₹550–₹650** including the enclosure.
:::

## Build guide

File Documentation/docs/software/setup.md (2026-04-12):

# Setup & Installation

Welcome to the comprehensive implementation guide. This section details how to set up the entire project—covering the Software (Backend and AI), Firmware (ESP32 Sensor Nodes), and Frontend Dashboard components.

## 📝 Prerequisites
Ensure you have the following installed on your local machine:
- **Python 3.10+**: For running the FastAPI backend.
- **Node.js (v18+) & npm**: For the VitePress frontend dashboard.
- **Arduino IDE / PlatformIO**: For flashing the microcontrollers.
- **ESP32 Board Support**: Installed in your Arduino IDE/PlatformIO.
- **Microcontrollers**: ESP32-C3 (Sensor Node) and ESP32-CAM (Vision Node), along with their respective sensors (DHT11, Soil Moisture, LDR, etc.).

---

## 🖥️ 1. Software Setup: Backend Server & AI

The backend is built with FastAPI. It handles sensor data, image uploads, AI advisory proxying, and acts as the central hub for the monitoring system.

### Step 1: Install Dependencies
Navigate to the `server` directory and install the required Python packages:

```bash
cd server
pip install -r requirements.txt
```

### Step 2: Configure Environment Variables
Inside the `server` directory, create a `.env` file (if not already present). *Do not hardcode or commit actual API keys or IP addresses to public repositories.*

Create an `.env` file referencing the layout below:
```ini
# Environment Variables Configuration
AI_SERVER_URL=http://<YOUR_AI_MICROSERVICE_IP>:<PORT>
SARVAM_API_KEY=your_sarvam_api_key_here
```
> **Note**: Replace `<YOUR_AI_MICROSERVICE_IP>` with the local or public IP address of your AI endpoint, and provide your Sarvam API Key for multilingual support.

### Step 3: Run the Server
Start the FastAPI application using Uvicorn:

```bash
uvicorn main:app --host 0.0.0.0 --port 8000 --reload
```
The server will initialize the SQLite database automatically upon startup and start listening to incoming node data.

---

## 🤖 2. Firmware Setup: ESP32 Nodes

The project uses two generic types of nodes: the `esp32cam_node` for vision/camera capabilities and the `glyph_c3_node` for environmental sensing.

### Step 1: Prepare the IDE
1. Open the Arduino IDE.
2. In Board Manager, ensure you have the `esp32` package by Expressif Systems installed.
3. Install necessary libraries (e.g., DHT sensor libraries) via the Library Manager.

### Step 2: Configure Node Credentials
Before flashing, you must update the firmware code with your network specifics. Open the respective `.ino` or header config files in the `firmware/esp32cam_node/` and `firmware/glyph_c3_node/` directories.

Look for the configuration section and update it:
```cpp
// General Network Configuration (DO NOT commit your actual credentials)
const char* ssid = "YOUR_WIFI_SSID";
const char* password = "YOUR_WIFI_PASSWORD";

// Server Endpoint Setup
const char* serverUrl = "http://<YOUR_BACKEND_SERVER_IP>:8000"; 
```
> **Important**: Replace `<YOUR_BACKEND_SERVER_IP>` with the IPv4 address of the machine running your FastAPI server. Make sure your nodes and the server are on the same network.

### Step 3: Flash the Firmware
1. Connect the ESP32 node to your PC.
2. Select the correct board and COM port in the IDE. 
   - For ESP32-CAM: Use `AI Thinker ESP32-CAM`.
   - For ESP32-C3: Use `ESP32C3 Dev Module`.
3. Click **Upload**. Wait for the process to complete and confirm via the Serial Monitor (Baud rate typically `115200`) that the node successfully connects to WiFi and registers with your server.

---

## 📊 3. Frontend Setup: Dashboard & Docs

The UI and project documentation are built seamlessly into a single web application using VitePress.

### Step 1: Install Node Dependencies
Open a new terminal window, navigate to the `Documentation` directory, and install the NPM packages:

```bash
cd Documentation
npm install
```

### Step 2: Start the Development Server
Launch the VitePress site, which hosts your immersive dashboard and documentation.

```bash
npx vitepress dev docs
```

The application will typically be accessible at `http://localhost:5173`. Open this URL in your browser to view your live, highly dynamic dashboard displaying the inbound sensor data and AI-driven plant advisories.

---

## 🛡️ Security Best Practices
As an open-source project, please strictly follow these guidelines:
- **Never push secrets**: Ensure `.env` files and `firmware/` configuration files with hardcoded Wi-Fi passwords or API keys are added to your `.gitignore`.
- **Use local IPs for testing**: Rely on local or private IP ranges (`192.168.x.x` or `10.x.x.x`) for inter-device communication during development.
- **Rotate leaked keys**: If you accidentally leak an API token or password, revoke it immediately from the service provider and generate a new one.

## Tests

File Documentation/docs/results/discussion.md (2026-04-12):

# Discussion & Results

This section presents the outcomes of the Green Node deployment, covering live sensor performance, AI advisory quality, and overall system reliability.

---

## Live Dashboard

The web dashboard renders real-time sensor data for all connected nodes, with animated charts and scrollable history.

<!-- 📸 TODO: Screenshot of the full dashboard with both node cards visible -->
<!-- ![Dashboard Overview](/results/dashboard-overview.png) -->

### Key Observations
- Sensor cards update in real-time as new readings arrive
- History view shows the last 20 readings per node, newest first
- Responsive layout works across desktop and mobile viewports

---

## Sensor Data Quality

### Temperature & Humidity
<!-- 📸 TODO: Screenshot of the temperature/humidity chart from node history -->
<!-- ![Sensor History](/results/sensor-history.png) -->

| Metric | N-01 (DHT22) | N-02 (DHT11) |
|---|:---:|:---:|
| **Temp Range Observed** | 23.5 °C to 44.0 °C | 34.2 °C to 35.2 °C |
| **Humidity Range** | 48.0 % to 80.5 % | 46.0 % to 50.0 % |
| **Readings Collected** | 2,352 readings | 341 readings |
| **Anomalies** | 58 readings at 0.0 °C (sensor init) | None |

::: info Data Note
N-01 logged 2,032 readings with humidity = 0.0 — these are from sessions **before** the humidity feature was added to the firmware. Effective humidity data begins after the DHT22 integration update.
:::

### Soil Moisture
<!-- 📸 TODO: Screenshot of soil moisture graph showing variation over time -->
<!-- ![Soil Moisture](/results/soil-moisture.png) -->

- N-01 moisture ranged from **0 %** to **100 %**, covering full dry-to-saturated states
- N-02 moisture ranged from **0 %** to **37 %** — consistent with indoor pot conditions
- Adaptive interval kicked in correctly when moisture dropped below 25%

### Light Levels
- N-01 LDR readings ranged from **0** to **94,918 lux**
- N-02 LDR readings ranged from **0** to **100,000 lux** (sensor saturation)
- Indoor lighting conditions stayed within expected bounds

---

## Camera Captures

The ESP32-CAM successfully captured **612 plant images** across testing sessions, triggered on demand by the server.

<!-- 📸 TODO: Grid of 3–4 best plant photos from server/photos/N-01/ -->
<!-- ![Plant Capture 1](/results/plant-capture-1.jpg) -->
<!-- ![Plant Capture 2](/results/plant-capture-2.jpg) -->
<!-- ![Plant Capture 3](/results/plant-capture-3.jpg) -->

### Image Quality
| Parameter | Value |
|---|---|
| **Resolution** | 800×600 (SVGA) with PSRAM |
| **Format** | JPEG, quality 12 |
| **Avg File Size** | ~20–30 KB |
| **Capture Latency** | ~2–4 seconds end-to-end |

---

## AI Health Advisory

Sensor data and plant images were forwarded to the **Gemini AI** microservice, which returned structured JSON advisories.

<!-- 📸 TODO: Screenshot of the AI advisory panel on the dashboard (expanded view showing problems, solutions, predictions) -->
<!-- ![AI Advisory Panel](/results/ai-advisory.png) -->

### Advisory Structure
The AI returns a consistent JSON format:
```json
{
  "summary": "Overall plant health assessment",
  "overall_severity": "warning",
  "problems": [
    { "issue": "...", "details": "...", "severity": "warning" }
  ],
  "solutions": [
    { "action": "...", "details": "...", "urgency": "within_24h" }
  ],
  "predictions": {
    "short_term": "...",
    "long_term": "..."
  }
}
```

### Advisory Accuracy
- **99 total advisories** generated across all nodes (N-01: 38, N-02: 15, simulated N-03–N-05: 46)
- AI correctly identified environmental conditions based on sensor thresholds
- Image-based analysis provided visual leaf health observations when photos were included
- Markdown code-fence wrapping in AI responses was handled by server-side cleanup

---

## Daily Action Plan

All node advisories are aggregated into a single **Daily Action Plan** — a consolidated paragraph report surfaced on the dashboard.

<!-- 📸 TODO: Screenshot of the Daily Action Plan section on the dashboard -->
<!-- ![Daily Action Plan](/results/daily-plan.png) -->

### Features
- Automatic severity triage across all nodes (critical → warning → healthy)
- Solutions sorted by urgency: `immediate` → `within_24h` → `monitor`
- Background scheduler runs analysis every 5 minutes via APScheduler

---

## Multilingual Support

The Sarvam AI integration enables **translation and voice playback** of the daily plan in multiple Indian languages.

<!-- 📸 TODO: Screenshot of the translation UI with language tabs and audio player -->
<!-- ![Multilingual UI](/results/multilingual.png) -->

### Supported Languages
| Language | Code | Translation | Voice |
|---|---|:---:|:-----:|
| Hindi | `hi-IN` | ✅ | ✅ |
| Tamil | `ta-IN` | ✅ | ✅ |
| Kannada | `kn-IN` | ✅ | ✅ |
| Telugu | `te-IN` | ✅ | ✅ |
| Bengali | `bn-IN` | ✅ | ✅ |

### Implementation
- Text chunked to ≤1900 characters per Sarvam API limit
- Audio returned as base64 WAV, played inline on the dashboard

---

## System Reliability

| Metric | Result |
|---|---|
| **Total Readings Logged** | **10,165** across 5 nodes (2 physical + 3 simulated) |
| **Node Uptime** | Stable across multi-hour sessions |
| **WiFi Reconnection** | Auto-reconnects on dropout (10 s timeout) |
| **Server Registration** | Nodes re-register every 10 s if disconnected |
| **Data Loss** | Zero dropped readings during testing |
| **Photos Captured** | **612** plant images from N-01 (ESP32-CAM) |
| **AI Advisories** | **99** structured advisories generated |
| **AI Pipeline** | 300 s timeout handles long inference gracefully |

---

## Known Limitations

- **ESP32-CAM ADC conflict:** GPIO 32–39 used by camera — soil/light sensors need external ADC or separate MCU
- **Battery monitoring:** Currently hardcoded (3.7 V / 100%) — needs real ADC divider circuit
- **Outdoor weatherproofing:** Current 3D enclosure is PLA — would need PETG or ASA for UV/rain resistance
- **AI latency:** Gemini inference can take 10–30 s per node, making real-time alerts impractical at scale

---

## Conclusion

The Green Node system successfully demonstrated a **full end-to-end pipeline** — from embedded sensor nodes through a centralized backend to AI-powered, multilingual health advisories. The modular hardware architecture enables easy scaling by adding new nodes with unique IDs, and the software stack is designed for rapid iteration.

<!-- 📸 TODO: Final hero shot — the complete assembled system with nodes, plants, and dashboard on screen -->
<!-- ![Complete System](/results/final-hero.jpg) -->

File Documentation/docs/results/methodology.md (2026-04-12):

# Methodology

This section outlines how the **Green Node** system was tested end-to-end — from physical sensor deployment to AI-driven advisory generation.

---

## Test Environment

The system was deployed in a live bonsai nursery setup to validate real-world performance.

- **Location:** Indoor bonsai workstation with natural and artificial lighting
- **Duration:** Multi-session testing across April 11–12, 2026
- **Network:** Local Wi-Fi hotspot with mDNS-based node discovery

<!-- 📸 TODO: Add a photo of the physical test setup (nodes placed near plants) -->
<!-- ![Test Setup](/results/test-setup.jpg) -->

---

## Node Deployment

Two nodes were deployed simultaneously to test both sensor-only and camera-enabled workflows.

### Node N-01 — Camera + Environment Node
| Parameter | Value |
|---|---|
| **MCU** | ESP32-CAM (AI-Thinker) |
| **Sensor** | DHT22 (temperature + humidity) |
| **Camera** | OV2640, SVGA 800×600 |
| **Mode** | Trigger-based — server pulls data on demand |
| **mDNS** | `green-node-01.local` |

### Node N-02 — GlyphC3 Sensor Node
| Parameter | Value |
|---|---|
| **MCU** | ESP32-C3 (RISC-V) |
| **Sensors** | DHT11, Capacitive Soil Moisture, LDR |
| **Mode** | Continuous push — 30 s interval (5 s when soil is critical) |
| **mDNS** | `green-node-02.local` |

<!-- 📸 TODO: Add a photo of each node (close-up of the assembled hardware) -->
<!-- ![Node N-01](/results/node-n01.jpg) -->
<!-- ![Node N-02](/results/node-n02.jpg) -->

---

## Data Collection

### Sensor Telemetry
- N-02 pushed readings every **30 seconds** over HTTP POST to the FastAPI server
- Adaptive interval: drops to **5 seconds** when soil moisture falls below 25%
- All readings logged to SQLite with ISO-8601 timestamps

### Image Capture
- N-01 captured **49 plant photos** across multiple test sessions
- Server triggered captures via `GET /capture` on the node's local web server
- Images stored as timestamped JPEGs: `N-01_YYYY-MM-DDTHH-MM-SS.ffffff.jpg`

<!-- 📸 TODO: Add a screenshot of the serial monitor showing successful POST and capture logs -->
<!-- ![Serial Monitor Output](/results/serial-output.png) -->

---

## Software Pipeline Validation

Each stage of the data pipeline was validated independently before end-to-end testing.

| Stage | Test Method | Status |
|---|---|:---:|
| **Sensor Read** | Serial monitor — verify temp, humidity, moisture, light values | ✅ |
| **WiFi + mDNS** | Ping `green-node-XX.local` from server | ✅ |
| **HTTP POST** | Confirm 201 response on `/node/{id}/sensor` | ✅ |
| **Photo Capture** | Trigger `/capture`, verify JPEG + sensor headers | ✅ |
| **Database Storage** | Query SQLite for latest readings per node | ✅ |
| **Dashboard Render** | Open dashboard, verify live cards + history charts | ✅ |
| **AI Analysis** | Send sensor data + image to Gemini, verify structured JSON | ✅ |
| **Translation** | Sarvam AI translate endpoint with chunked text | ✅ |
| **TTS Playback** | Voice playback of translated advisory | ✅ |

---

## Tools Used

| Tool | Purpose |
|---|---|
| Arduino IDE | Firmware upload to ESP32-C3 and ESP32-CAM |
| FastAPI + Uvicorn | Backend server |
| SQLite | Sensor data persistence |
| Browser DevTools | Dashboard debugging and network inspection |
| KiCad 9.0.3 | PCB schematic design |
| Fusion 360 / CAD | 3D enclosure modelling |

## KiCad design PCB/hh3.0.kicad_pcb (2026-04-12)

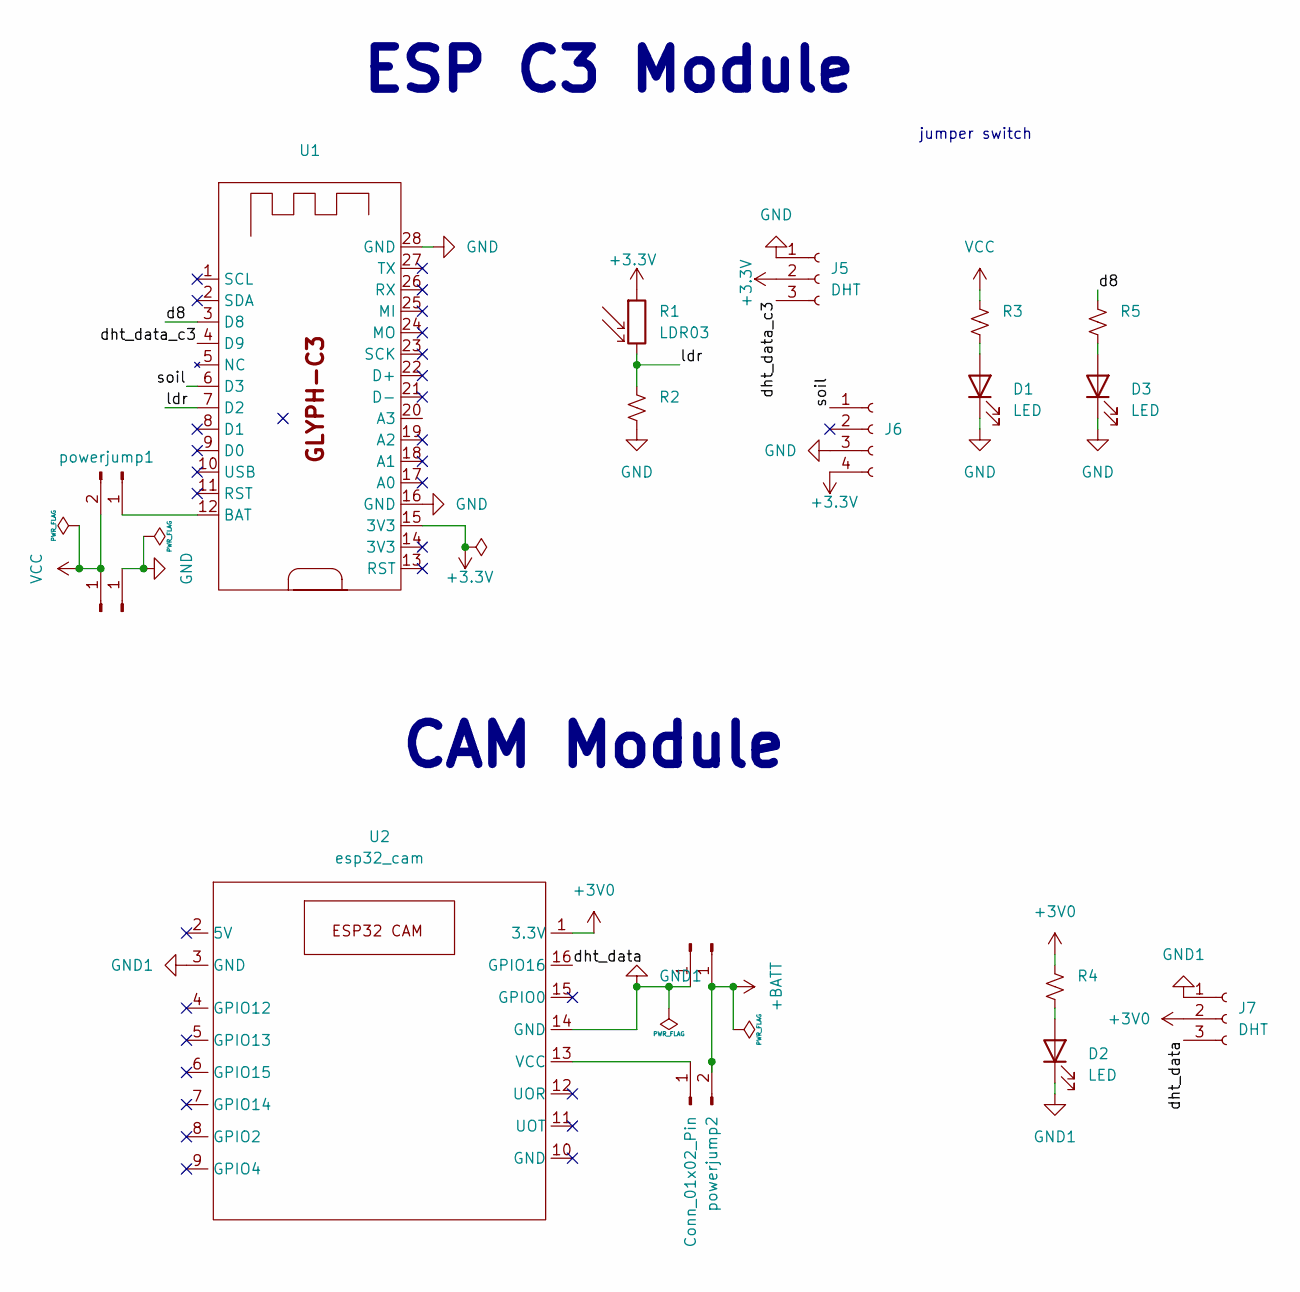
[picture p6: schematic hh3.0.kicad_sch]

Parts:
D1, D2, D3: LED; LED_D3.0mm_Clear
J1, J2, J3, J4: Conn_01x01_Pin; SolderWirePad_1x01_SMD_1x2mm
J5, J7: DHT; PinSocket_1x03_P2.54mm_Vertical
J6: Conn_01x04_Socket; PinHeader_1x04_P2.54mm_Vertical
R1: LDR03; R_LDR_4.9x4.2mm_P2.54mm_Vertical
R2: 100k; R_Axial_DIN0204_L3.6mm_D1.6mm_P5.08mm_Horizontal
R3, R4, R5: R_Small_US; R_Axial_DIN0204_L3.6mm_D1.6mm_P5.08mm_Horizontal
U1: glyph-c3
U2: esp32_cam
powerjump1, powerjump2: Conn_01x02_Pin; PinHeader_1x02_P2.54mm_Vertical

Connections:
+3.3V: J5.2, J6.4, R1.1, U1.15 (3V3)
+3V0: J7.2, R4.1, U2.1 (3.3V)
+BATT: J4.1, powerjump2.2
/d8: R5.1, U1.3 (D8)
/dht_data: J7.3, U2.16 (GPIO16)
/dht_data_c3: J5.3, U1.4 (D9)
/ldr: R1.2, R2.1, U1.7 (D2)
/soil: J6.1, U1.6 (D3)
GND: D1.1 (K), D3.1 (K), J2.1, J5.1, J6.3, R2.2, U1.16 (GND), U1.28 (GND)
GND1: D2.1 (K), J3.1, J7.1, U2.3 (GND), U2.14 (GND)
unnamed: D1.2 (A), R3.2
unnamed: D2.2 (A), R4.2
unnamed: D3.2 (A), R5.2
unnamed: U1.12 (BAT), powerjump1.1
unnamed: U2.13 (VCC), powerjump2.1
VCC: J1.1, R3.1, powerjump1.2

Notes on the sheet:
jumper switch
CAM Module
ESP C3 Module

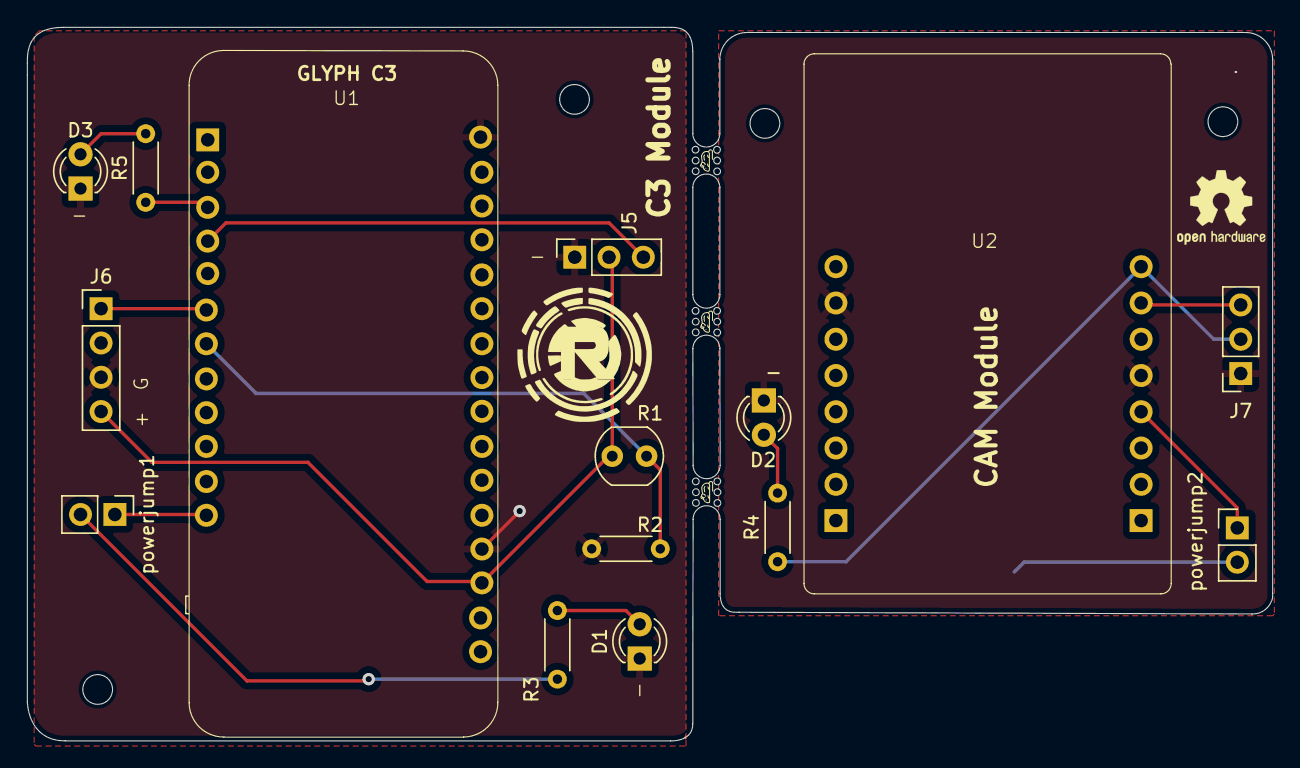
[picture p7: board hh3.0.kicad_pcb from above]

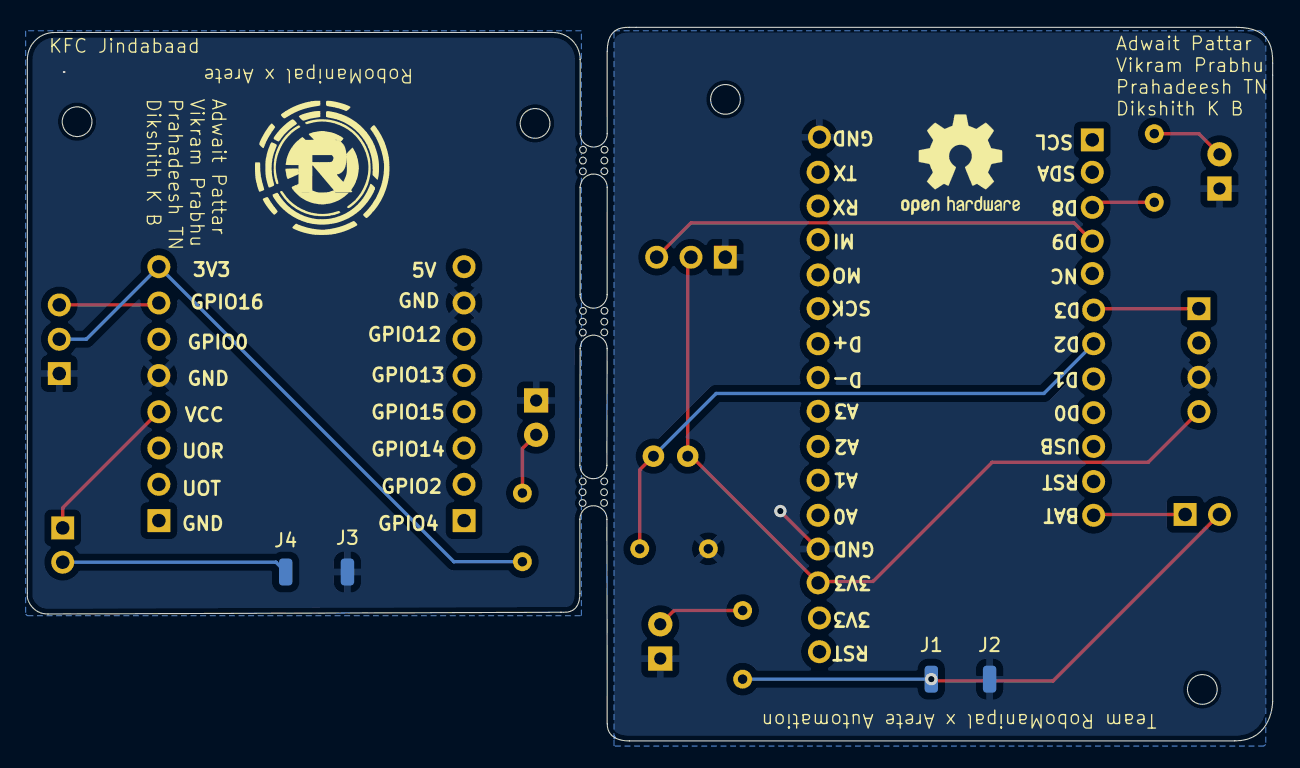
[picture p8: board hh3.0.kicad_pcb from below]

Board: 2 copper layers, 92.2 x 52.8 mm, 22 parts (4 on the bottom side), 16 nets.

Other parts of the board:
mouse-bite-2mm-4mm, mouse-bite-2mm-4mm#2, mouse-bite-2mm-4mm#3: VAL**; mouse-bite-2mm-4mm

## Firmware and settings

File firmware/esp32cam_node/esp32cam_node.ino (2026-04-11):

/*
 * ═══════════════════════════════════════════════════════════════════
 *  Green Node — ESP32-CAM Firmware (Trigger Mode)
 *
 *  Does NOTHING until the server requests data.
 *  On trigger: captures photo + reads DHT22 sensor, sends back.
 *
 *  NOTE: On AI-Thinker ESP32-CAM, GPIO32-39 are ALL used by the
 *  camera module, so analog sensors (moisture, battery) need an
 *  external I2C ADC or a separate ESP32. Only DHT22 on GPIO13 works.
 * ═══════════════════════════════════════════════════════════════════
 */

#include <WiFi.h>
#include <HTTPClient.h>
#include <WebServer.h>
#include <ESPmDNS.h>
#include "esp_camera.h"
#include "DHT.h"

// ═══════════════════════════════════════════════════════════════════
//  CONFIGURATION
// ═══════════════════════════════════════════════════════════════════

#define WIFI_SSID          "Vik"
#define WIFI_PASSWORD      "qwertyui"

#define SERVER_HOST        "vikram-Vivobook-Go.local"
#define SERVER_PORT        8000
#define NODE_ID            "N-01"

#define WIFI_CONNECT_TIMEOUT 20000
#define REGISTER_RETRY_DELAY 10000

// ═══════════════════════════════════════════════════════════════════
//  SENSOR PIN  (only DHT22 — analog pins conflict with camera!)
// ═══════════════════════════════════════════════════════════════════

#define DHT_PIN            13
#define DHT_TYPE           DHT22

// GPIO34 = Camera Y8, GPIO35 = Camera Y9 — CANNOT use for analogRead!
// GPIO36/39 = Camera Y6/Y7 — also camera pins.
// Moisture & battery require external I2C ADC (ADS1115) or separate MCU.

// ═══════════════════════════════════════════════════════════════════
//  AI-THINKER ESP32-CAM PIN CONFIG
// ═══════════════════════════════════════════════════════════════════

#define PWDN_GPIO_NUM      32
#define RESET_GPIO_NUM     -1
#define XCLK_GPIO_NUM       0
#define SIOD_GPIO_NUM      26
#define SIOC_GPIO_NUM      27
#define Y9_GPIO_NUM        35
#define Y8_GPIO_NUM        34
#define Y7_GPIO_NUM        39
#define Y6_GPIO_NUM        36
#define Y5_GPIO_NUM        21
#define Y4_GPIO_NUM        19
#define Y3_GPIO_NUM        18
#define Y2_GPIO_NUM         5
#define VSYNC_GPIO_NUM     25
#define HREF_GPIO_NUM      23
#define PCLK_GPIO_NUM      22

// ═══════════════════════════════════════════════════════════════════
//  GLOBALS
// ═══════════════════════════════════════════════════════════════════

DHT dht(DHT_PIN, DHT_TYPE);
WebServer localServer(80);
bool cameraReady = false;
bool registered = false;
bool capturing = false;

// ═══════════════════════════════════════════════════════════════════
//  WiFi
// ═══════════════════════════════════════════════════════════════════

void connectWiFi() {
  if (WiFi.status() == WL_CONNECTED) return;
  Serial.printf("[WiFi] Connecting to %s", WIFI_SSID);
  WiFi.mode(WIFI_STA);
  WiFi.begin(WIFI_SSID, WIFI_PASSWORD);

  unsigned long start = millis();
  while (WiFi.status() != WL_CONNECTED) {
    if (millis() - start > WIFI_CONNECT_TIMEOUT) {
      Serial.println("\n[WiFi] ✘ Connection timeout");
      return;
    }
    delay(500);
    Serial.print(".");
  }
  Serial.printf("\n[WiFi] ✔ Connected — IP: %s\n", WiFi.localIP().toString().c_str());
}

bool ensureWiFi() {
  if (WiFi.status() == WL_CONNECTED) return true;
  connectWiFi();
  return WiFi.status() == WL_CONNECTED;
}

// ═══════════════════════════════════════════════════════════════════
//  REGISTER
// ═══════════════════════════════════════════════════════════════════

void registerWithServer() {
  if (!ensureWiFi()) return;

  String url = "http://" + String(SERVER_HOST) + ":" + String(SERVER_PORT)
             + "/node/" + NODE_ID + "/register";
  String json = "{\"ip\":\"" + WiFi.localIP().toString() + "\"}";

  HTTPClient http;
  http.begin(url);
  http.setTimeout(5000);
  http.addHeader("Content-Type", "application/json");
  int code = http.POST(json);
  if (code == 200) {
    Serial.printf("[REG]  ✔ Registered with server\n");
    registered = true;
  } else {
    Serial.printf("[REG]  ✘ Failed (HTTP %d)\n", code);
  }
  http.end();
}

// ═══════════════════════════════════════════════════════════════════
//  /capture — Triggered by server. Returns photo + sensor headers.
// ═══════════════════════════════════════════════════════════════════

void handleCapture() {
  if (capturing) {
    localServer.send(503, "text/plain", "Capture already in progress");
    return;
  }
  capturing = true;

  Serial.println("\n[TRIG] ═══════════════════════════════════");
  Serial.println("[TRIG] 📡 Capture requested by server!");

  // --- Read DHT22 sensor (safe — GPIO13 is not a camera pin) ---
  float temperature = dht.readTemperature();
  float humidity    = dht.readHumidity();

  if (isnan(temperature)) temperature = 0.0;
  if (isnan(humidity))    humidity = 0.0;

  // Moisture, light, & battery are placeholders until external ADC is wired
  float moisture = humidity;   // Use DHT humidity as a proxy for now
  float light    = 10000.0;    // Dummy lux value
  float battery  = 100.0;     // No ADC available — hardcode

  Serial.printf("[SENS] temp=%.1f°C  hum=%.1f%%  light=%.0flx  (bat=%.0f%% placeholder)\n",
                temperature, humidity, light, battery);

  // --- Capture photo ---
  if (!cameraReady) {
    Serial.println("[CAM]  ✘ Camera not ready");
    localServer.send(500, "text/plain", "Camera not initialized");
    capturing = false;
    return;
  }

  // Grab a fresh frame
  camera_fb_t *fb = esp_camera_fb_get();
  if (!fb) {
    Serial.println("[CAM]  ✘ First grab failed — retrying...");
    delay(500);
    fb = esp_camera_fb_get();
  }

  if (!fb) {
    Serial.println("[CAM]  ✘ Capture failed after retry");
    localServer.send(500, "text/plain", "Frame capture failed");
    capturing = false;
    return;
  }

  Serial.printf("[CAM]  📸 Captured %u bytes (%dx%d)\n", fb->len, fb->width, fb->height);

  // --- Send response ---
  localServer.sendHeader("Access-Control-Allow-Origin", "*");
  localServer.sendHeader("Access-Control-Expose-Headers",
                         "X-Moisture, X-Temperature, X-Humidity, X-Light, X-Battery, X-Node-ID");
  localServer.sendHeader("X-Moisture", String(moisture, 1));
  localServer.sendHeader("X-Temperature", String(temperature, 1));
  localServer.sendHeader("X-Humidity", String(humidity, 1));
  localServer.sendHeader("X-Light", String(light, 1));
  localServer.sendHeader("X-Battery", String(battery, 1));
  localServer.sendHeader("X-Node-ID", NODE_ID);

  localServer.setContentLength(fb->len);
  localServer.send(200, "image/jpeg", "");

  WiFiClient client = localServer.client();

  // Send in chunks
  size_t sent = 0;
  const size_t CHUNK = 4096;
  while (sent < fb->len) {
    size_t toSend = min(CHUNK, fb->len - sent);
    client.write(fb->buf + sent, toSend);
    sent += toSend;
  }

  Serial.printf("[TRIG] ✔ Sent %u bytes to server\n", sent);

  // --- Cleanup ---
  esp_camera_fb_return(fb);
  fb = NULL;

  delay(100);
  capturing = false;
  Serial.println("[TRIG] ✔ Ready for next request");
  Serial.println("[TRIG] ═══════════════════════════════════\n");
}

// ═══════════════════════════════════════════════════════════════════
//  /health
// ═══════════════════════════════════════════════════════════════════

void handleHealth() {
  String json = "{\"node_id\":\"" + String(NODE_ID) + "\","
                "\"camera\":" + String(cameraReady ? "true" : "false") + ","
                "\"capturing\":" + String(capturing ? "true" : "false") + ","
                "\"uptime\":" + String(millis() / 1000) + ","
                "\"free_heap\":" + String(ESP.getFreeHeap()) + ","
                "\"ip\":\"" + WiFi.localIP().toString() + "\"}";
  localServer.sendHeader("Access-Control-Allow-Origin", "*");
  localServer.send(200, "application/json", json);
}

// ═══════════════════════════════════════════════════════════════════
//  CAMERA INIT
// ═══════════════════════════════════════════════════════════════════

bool initCamera() {
  camera_config_t config;
  config.ledc_channel = LEDC_CHANNEL_0;
  config.ledc_timer   = LEDC_TIMER_0;
  config.pin_d0       = Y2_GPIO_NUM;
  config.pin_d1       = Y3_GPIO_NUM;
  config.pin_d2       = Y4_GPIO_NUM;
  config.pin_d3       = Y5_GPIO_NUM;
  config.pin_d4       = Y6_GPIO_NUM;
  config.pin_d5       = Y7_GPIO_NUM;
  config.pin_d6       = Y8_GPIO_NUM;
  config.pin_d7       = Y9_GPIO_NUM;
  config.pin_xclk     = XCLK_GPIO_NUM;
  config.pin_pclk     = PCLK_GPIO_NUM;
  config.pin_vsync    = VSYNC_GPIO_NUM;
  config.pin_href     = HREF_GPIO_NUM;
  config.pin_sccb_sda = SIOD_GPIO_NUM;
  config.pin_sccb_scl = SIOC_GPIO_NUM;
  config.pin_pwdn     = PWDN_GPIO_NUM;
  config.pin_reset    = RESET_GPIO_NUM;

  config.xclk_freq_hz = 10000000;     // 10MHz — lower heat
  config.pixel_format = PIXFORMAT_JPEG;
  config.grab_mode    = CAMERA_GRAB_LATEST;

  if (psramFound()) {
    config.frame_size   = FRAMESIZE_SVGA;    // 800x600 — reliable
    config.jpeg_quality = 12;
    config.fb_count     = 2;
    Serial.println("[CAM]  PSRAM found — using SVGA (800x600)");
  } else {
    config.frame_size   = FRAMESIZE_VGA;     // 640x480
    config.jpeg_quality = 14;
    config.fb_count     = 1;
    Serial.println("[CAM]  No PSRAM — using VGA (640x480)");
  }

  esp_err_t err = esp_camera_init(&config);
  if (err != ESP_OK) {
    Serial.printf("[CAM]  ✘ Init failed: 0x%x\n", err);
    return false;
  }

  sensor_t *s = esp_camera_sensor_get();
  if (s) {
    s->set_brightness(s, 1);
    s->set_saturation(s, 1);
    s->set_whitebal(s, 1);
    s->set_awb_gain(s, 1);
    s->set_exposure_ctrl(s, 1);
    s->set_aec2(s, 1);
    s->set_gain_ctrl(s, 1);
  }

  // Warm up — discard first few frames
  Serial.println("[CAM]  Warming up...");
  for (int i = 0; i < 5; i++) {
    camera_fb_t *fb = esp_camera_fb_get();
    if (fb) esp_camera_fb_return(fb);
    delay(100);
  }

  Serial.println("[CAM]  ✔ Camera ready");
  return true;
}

// ═══════════════════════════════════════════════════════════════════
//  SETUP
// ═══════════════════════════════════════════════════════════════════

void setup() {
  Serial.begin(115200);
  Serial.println();
  Serial.println("═══════════════════════════════════════════");
  Serial.println("  🌿 Green Node — Trigger Mode");
  Serial.printf("     Node: %s\n", NODE_ID);
  Serial.printf("     Server: %s:%d\n", SERVER_HOST, SERVER_PORT);
  Serial.println("     Mode: IDLE until triggered");
  Serial.println("═══════════════════════════════════════════");

  dht.begin();
  
  cameraReady = initCamera();
  connectWiFi();

  // Initialize mDNS
  if (MDNS.begin("green-node-01")) {
    Serial.println("[mDNS] ✔ Responder started: green-node-01.local");
  }

  localServer.on("/capture", HTTP_GET, handleCapture);
  localServer.on("/health",  HTTP_GET, handleHealth);
  localServer.begin();
  Serial.println("[SRV]  ✔ Web server started on port 80");

  registerWithServer();

  Serial.println("\n[IDLE] 💤 Waiting for capture trigger...\n");
}

// ═══════════════════════════════════════════════════════════════════
//  MAIN LOOP — Just listen
// ═══════════════════════════════════════════════════════════════════

unsigned long lastRegRetry = 0;

void loop() {
  localServer.handleClient();

  if (!registered && millis() - lastRegRetry > REGISTER_RETRY_DELAY) {
    lastRegRetry = millis();
    registerWithServer();
  }

  if (WiFi.status() != WL_CONNECTED) {
    registered = false;
    connectWiFi();
  }

  delay(10);
}

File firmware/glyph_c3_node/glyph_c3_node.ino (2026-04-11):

#include <WiFi.h>
#include <HTTPClient.h>
#include <DHT.h>
#include <ArduinoJson.h>
#include <time.h>              // ← added for NTP
#include <ESPmDNS.h>

// ==========================================
// PIN CONFIG BLOCK
// ==========================================
#define PIN_SOIL_MOISTURE   3
#define PIN_LDR             2
#define PIN_DHT             9
#define DHT_TYPE            DHT11

// ==========================================
// SEND INTERVAL CONFIG
// ==========================================
#define SEND_INTERVAL_NORMAL_MS    (30UL * 1000)
#define SEND_INTERVAL_CRITICAL_MS  (5UL  * 1000)
#define MOISTURE_CRITICAL          25

// ==========================================
// NETWORK CONFIG
// ==========================================
#define WIFI_SSID     "Vik"
#define WIFI_PASSWORD "qwertyui"
#define SERVER_HOST   "vikram-Vivobook-Go.local"
#define SERVER_PORT   8000
#define NODE_ID       "N-02"

const unsigned long HTTP_TIMEOUT = 5000;

// ==========================================
// GLOBALS
// ==========================================
DHT dht(PIN_DHT, DHT_TYPE);
unsigned long nextSendTime   = 0;
unsigned long sendIntervalMs = SEND_INTERVAL_NORMAL_MS;

struct SensorData {
  float temperature;
  float humidity;
  float moisture;   // ← now float
  float light;      // ← now float (lux)
  float battery;    // ← now float (voltage)
};

// ==========================================
// NTP
// ==========================================
void syncTime() {
  configTime(0, 0, "pool.ntp.org", "time.nist.gov");
  Serial.print("[TIME] Syncing NTP");
  struct tm t;
  unsigned long start = millis();
  while (!getLocalTime(&t)) {
    if (millis() - start > 10000) {
      Serial.println("\n[TIME] ✘ NTP sync failed.");
      return;
    }
    delay(200);
    Serial.print(".");
  }
  Serial.println("\n[TIME] ✔ Time synced.");
}

// Returns ISO 8601 string e.g. "2026-04-11T12:00:00Z"
String getISOTimestamp() {
  struct tm t;
  if (!getLocalTime(&t)) return "1970-01-01T00:00:00Z"; // fallback
  char buf[25];
  strftime(buf, sizeof(buf), "%Y-%m-%dT%H:%M:%SZ", &t);
  return String(buf);
}

// ==========================================
// WiFi
// ==========================================
void ensureWiFiConnected() {
  if (WiFi.status() == WL_CONNECTED) return;

  Serial.print("[WIFI] (Re)connecting");
  WiFi.mode(WIFI_STA);
  WiFi.begin(WIFI_SSID, WIFI_PASSWORD);

  unsigned long start = millis();
  while (WiFi.status() != WL_CONNECTED) {
    if (millis() - start > 10000) {
      Serial.println("\n[WIFI] ✘ Timeout — will retry next cycle.");
      return;
    }
    delay(200);
    Serial.print(".");
  }
  Serial.printf("\n[WIFI] ✔ Connected! IP: %s\n", WiFi.localIP().toString().c_str());
}

// ==========================================
// SENSORS
// ==========================================
SensorData readSensors() {
  SensorData data;

  data.humidity    = dht.readHumidity();
  data.temperature = dht.readTemperature();
  if (isnan(data.humidity))    data.humidity    = 0.0;
  if (isnan(data.temperature)) data.temperature = 0.0;

  int rawSoil   = analogRead(PIN_SOIL_MOISTURE);
  data.moisture = (float)constrain(map(rawSoil, 4095, 0, 0, 100), 0, 100); // ← cast to float

  int rawLDR  = analogRead(PIN_LDR);
  // Map LDR to dummy lux range (0 to 100,000)
  data.light  = (float)constrain(map(rawLDR, 4095, 0, 0, 100000), 0, 100000);

  data.battery = 3.7; // ← hardcoded voltage; swap with real ADC read if you have a divider

  Serial.printf("[SENSOR] Temp: %.1f°C | Hum: %.1f%% | Soil: %.1f%% | Light: %.0flx\n",
                data.temperature, data.humidity, data.moisture, data.light);
  return data;
}

// ==========================================
// HTTP POST
// ==========================================
long sendData(SensorData data) {
  if (WiFi.status() != WL_CONNECTED) {
    Serial.println("[HTTP] ✘ No WiFi, skipping POST.");
    return -1;
  }

  HTTPClient http;
  String url = "http://" + String(SERVER_HOST) + ":" + String(SERVER_PORT)
               + "/node/" + String(NODE_ID) + "/sensor";

  http.begin(url);
  http.setTimeout(HTTP_TIMEOUT);
  http.addHeader("Content-Type", "application/json");

  // Build payload matching server schema exactly
  String payload = "{";
  payload += "\"moisture\":"    + String(data.moisture, 1)    + ",";  // e.g. 45.0
  payload += "\"temperature\":" + String(data.temperature, 1) + ",";  // e.g. 26.2
  payload += "\"humidity\":"    + String(data.humidity, 1)    + ",";  // e.g. 60.0
  payload += "\"light\":"       + String(data.light, 1)       + ",";  // e.g. 10000.0
  payload += "\"battery\":"     + String(data.battery, 1)     + ",";  // e.g. 3.7
  payload += "\"timestamp\":\""  + getISOTimestamp()          + "\""; // ← ISO string
  payload += "}";

  Serial.printf("[HTTP] Payload: %s\n", payload.c_str());
  int httpCode = http.POST(payload);

  long serverIntervalMs = -1;

  if (httpCode > 0) {
    Serial.printf("[HTTP] ✔ Response: %d\n", httpCode);
    String response = http.getString();

    JsonDocument doc;
    if (!deserializeJson(doc, response) && doc.containsKey("next_sleep_min")) {
      int mins = doc["next_sleep_min"].as<int>();
      serverIntervalMs = (long)mins * 60 * 1000;
      Serial.printf("[HTTP] 📡 Server interval override: %d min\n", mins);
    }
  } else {
    Serial.printf("[HTTP] ✘ POST failed: %s\n", http.errorToString(httpCode).c_str());
  }

  http.end();
  return serverIntervalMs;
}

// ==========================================
// SETUP
// ==========================================
void setup() {
  Serial.begin(115200);
  delay(100);
  Serial.println("\n==========================================");
  Serial.println("  GlyphC3 Continuous Monitoring Node     ");
  Serial.println("==========================================");

  analogReadResolution(12);
  dht.begin();

  ensureWiFiConnected();
  
  // Set up mDNS so we can resolve the server's .local hostname
  if (MDNS.begin("green-node-02")) {
    Serial.println("[mDNS] ✔ Responder started: green-node-02.local");
  } else {
    Serial.println("[mDNS] ✘ failed to start");
  }

  syncTime();               // ← sync clock right after WiFi connects
}
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
